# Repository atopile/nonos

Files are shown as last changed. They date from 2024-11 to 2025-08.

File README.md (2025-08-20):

# NONOS

### The Open Source Smart Speaker

<div align="center">
  
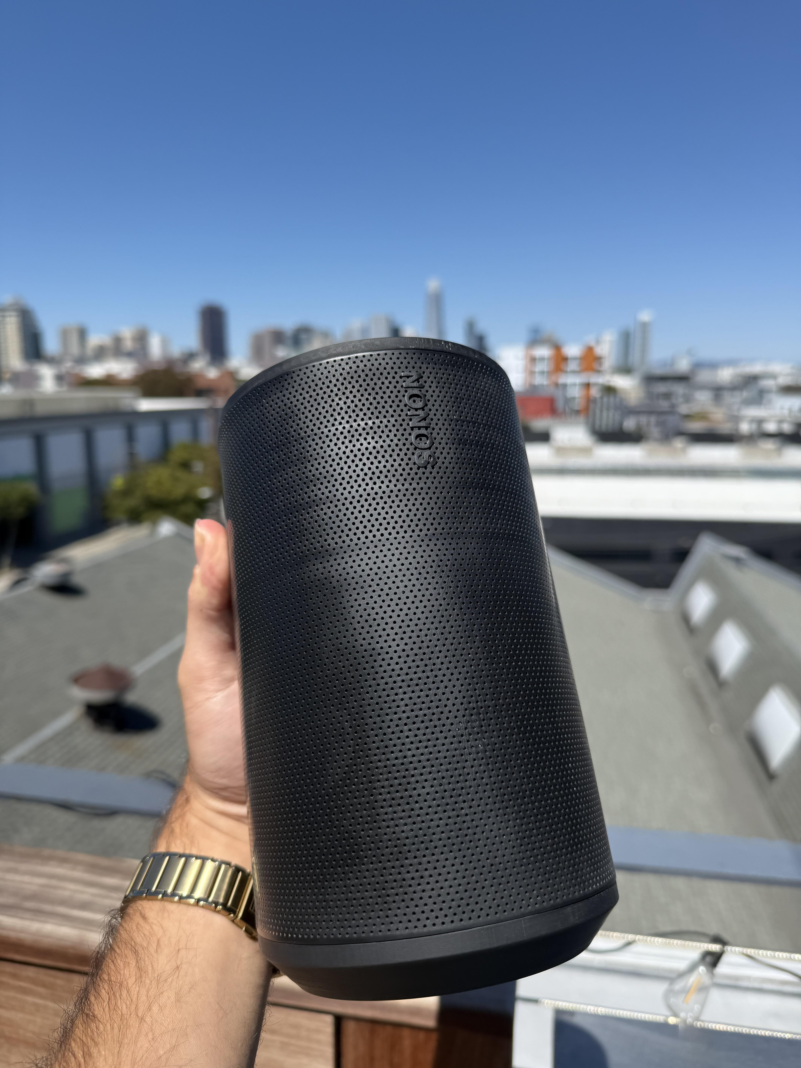
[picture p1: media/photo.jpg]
NONOS Smart Speaker
  
  
  **Premium Sound • Privacy First • Fully Hackable**
  
  
  
  
  
</div>

---

## 🎵 Experience Audio Freedom

NONOS is a premium smart speaker that puts you in control. It delivers exceptional sound quality while respecting your privacy, and its hardware is described declaratively in lightweight `.ato` files.

### ✨ Key Features

<table>
<tr>
<td width="50%">

**🔊 Audiophile-Grade Sound**

- Dual-driver system with dedicated tweeter and full-range speaker
- Texas Instruments TAS5825M Class-D amplifier
- Analog Devices ADAU145x DSP for pristine audio processing
- I2S digital audio interface for lossless playback

</td>
<td width="50%">

**🧠 Powerful Computing**

- Raspberry Pi CM5 module at its heart
- Gigabit Ethernet connectivity
- USB-C with Power Delivery support
- Multiple I2C, UART, and GPIO interfaces

</td>
</tr>
<tr>
<td width="50%">

**🎨 Interactive Design**

- 23 SK6805 addressable RGB LEDs
- Capacitive touch controls with volume slider
- NFC tap-to-pair functionality
- Minimalist cylindrical form factor

</td>
<td width="50%">

**⚡ Smart Power Management**

- USB-C Power Delivery (20V input)
- Efficient buck converters (5V & 3.3V rails)
- STUSB4500 PD controller
- Low standby power consumption

</td>
</tr>
</table>

---

## 🎶 Software Features

### Streaming Services

Connect and play from all your favorite sources:

- **Spotify Connect** - Stream directly from the Spotify app
- **AirPlay** - Native support for Apple devices
- **Bluetooth Audio** - Auto-pairing A2DP streaming
- **Local Playback** - Play your music library via network shares

### Smart Controls

Intuitive touch interface with gesture support:

- **Play/Pause** - Center button for media control
- **Track Navigation** - Skip tracks or seek within songs
- **Volume Slider** - 5-position touch slider with double-tap gestures
  - Double-tap position 0 for mute
  - Double-tap position 4 for +6dB boost
- **Configurable EQ** - 15-band parametric equalizer

### Audio Excellence

Professional-grade DSP processing:

- **Crossover Networks** - Optimized for dual-driver configuration
- **Dynamic Range Control** - Independent limiting for highs and lows
- **Mid-Side Processing** - Adjustable stereo width
- **PipeWire Integration** - Low-latency audio with automatic resampling

---

## 🎛️ Hardware Highlights

### Audio Processing Pipeline

```
CM5 (Digital Audio) → I2S → ADAU145x DSP → I2S → TAS5825M Amplifier → Speakers
```

### Interactive Hat Module

- **NFC**: PN5321 for instant device pairing
- **Touch**: CAP1188 capacitive sensor (3 buttons + 5-position slider)
- **LEDs**: 23x SK6805 RGB LEDs in a circular array
- **Level Shifting**: Ensures reliable 3.3V/5V communication

### Debug Headers

Three Saleae-compatible headers for easy development:

- UART console access
- I2C bus monitoring
- I2S audio stream analysis

### Printed Circuit Boards

#### Mainboard

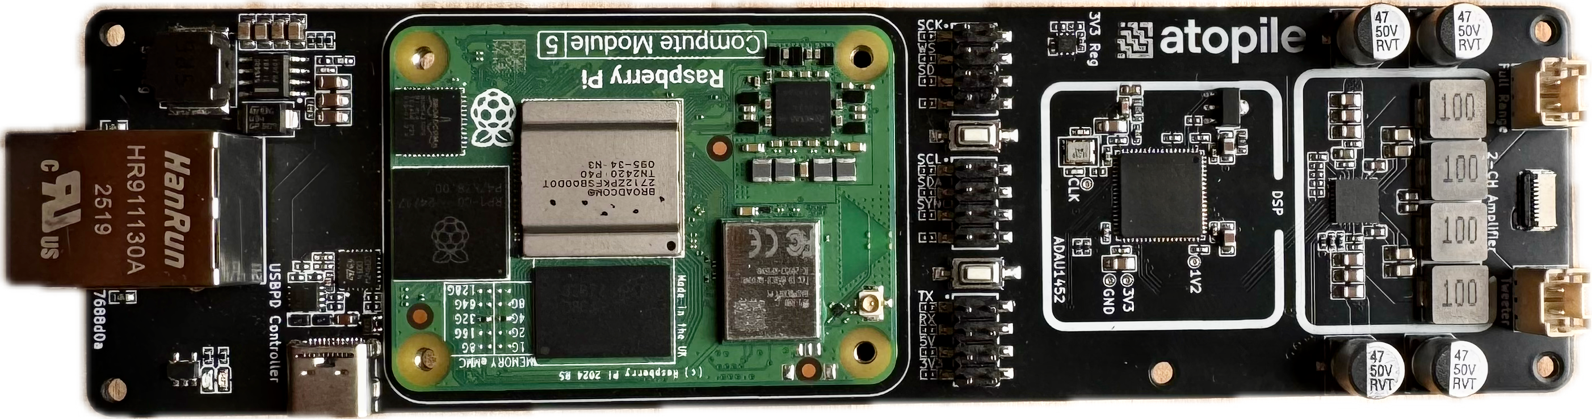
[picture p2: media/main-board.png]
NONOS Mainboard Render


- **atopile module:** `NONOS` (`elec/src/nonos.ato`)
- USB-C Power Delivery input via **STUSB4500** (up to 20 V)
- Power tree: **TPS54560x** 5 V buck ➜ **TLV75901** 3 .3 V LDO
- **Raspberry Pi CM5** compute module
- **ADAU145x** audio DSP ➜ **TAS5825M** 2-channel Class-D amplifier
- 10-pin mezzanine connector to the Hat
- Connectors for full-range & tweeter speakers
- Three Saleae-compatible debug headers (UART, I2C, I2S)

#### Control Hat

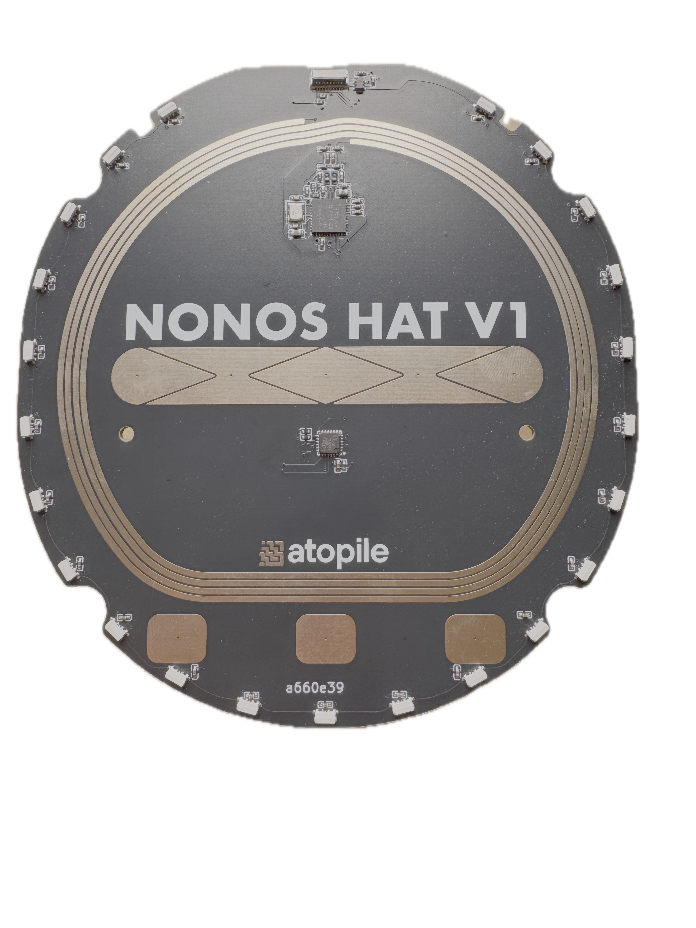
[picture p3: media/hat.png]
Interactive Hat PCB


- **atopile module:** `Hat` (`elec/src/hat.ato`)
- **PN5321** NFC transceiver with custom button-antenna
- **CAP1188** capacitive touch sensor (3 buttons + 5-point slider)
- 23× **SK6805** side-emitting RGB LEDs arranged in a ring
- **74LVC1T45** level-shifter for reliable 5 V LED data
- Powered from 3 .3 V (logic) & 5 V (LEDs) supplied by the mainboard
- 10-pin mezzanine connector mates directly with the mainboard

---

## 🛠️ Hardware Design

The hardware is captured in concise `.ato` design files (powered by [atopile](https://atopile.io)).

```ato
module NONOS:
    """
    An opensource sonos era 100 clone
    """

    # Core Components
    cm5 = new CM5
    amplifier = new Texas_Instruments_TAS5825MRHBR_driver
    dsp = new Analog_Devices_ADAU145x_driver
    pd_controller = new STUSB4500

    # Smart Power Distribution
    pd_controller.power_out ~ power_20v
    power_20v ~> regulator_5v ~> power_5v
    power_5v ~> regulator_3v3 ~> power_3v3
```

### 📁 Project Structure

```
nonos/
├── elec/
│   └── src/
│       ├── nonos.ato      # Main speaker module
│       ├── hat.ato        # Touch/LED/NFC interface
│       └── parts/         # Component library
├── firmware/              # CM5 software stack
├── mechanical/            # Enclosure designs
└── docs/                  # Build instructions
```

---

## 🎚️ Audio Tuning

<table>
<tr>
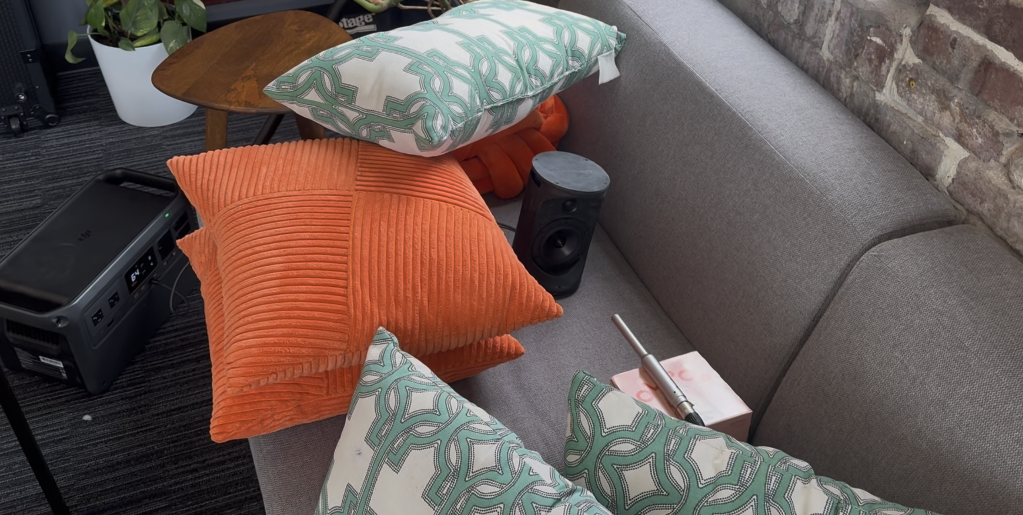
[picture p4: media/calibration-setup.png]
Calibration setup
<td width="33%"></td>
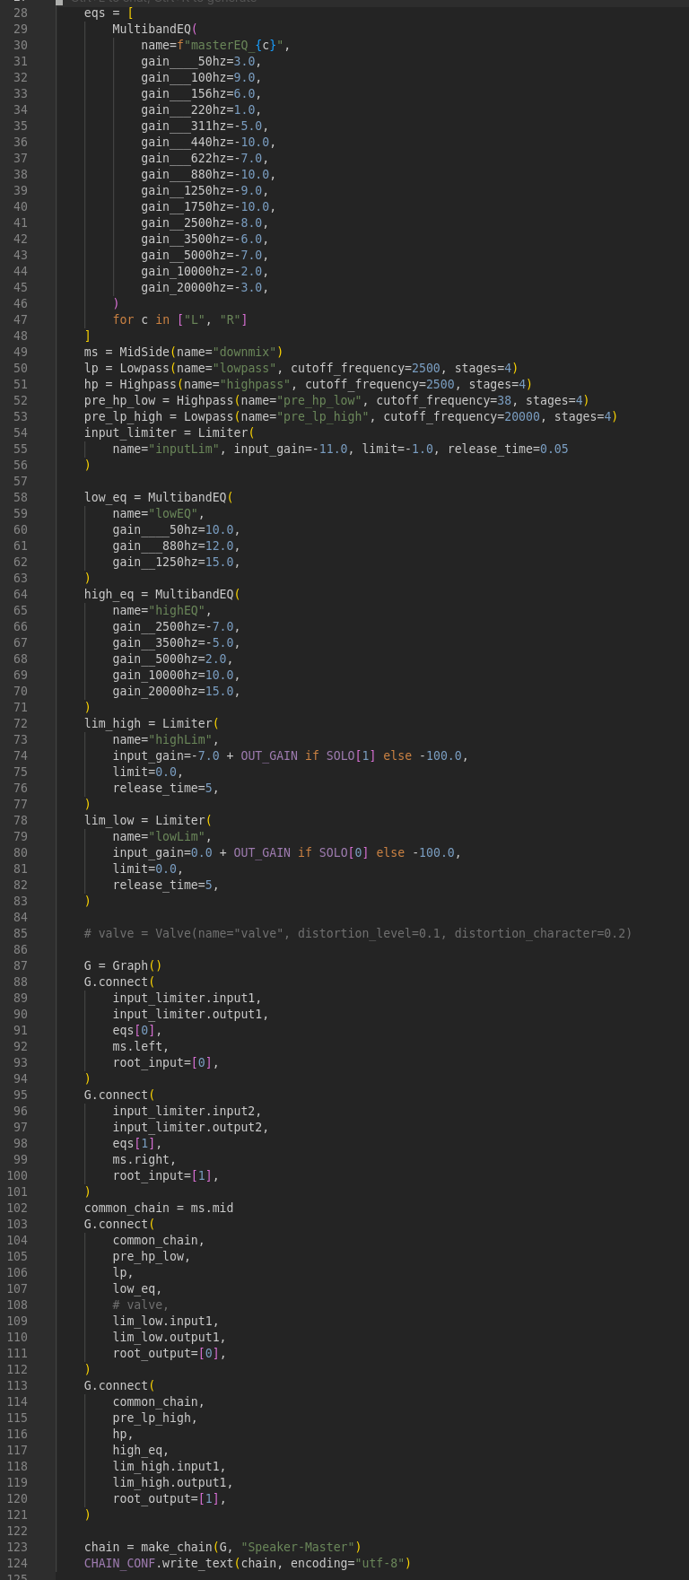
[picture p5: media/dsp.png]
DSP tuning
<td width="33%"></td>
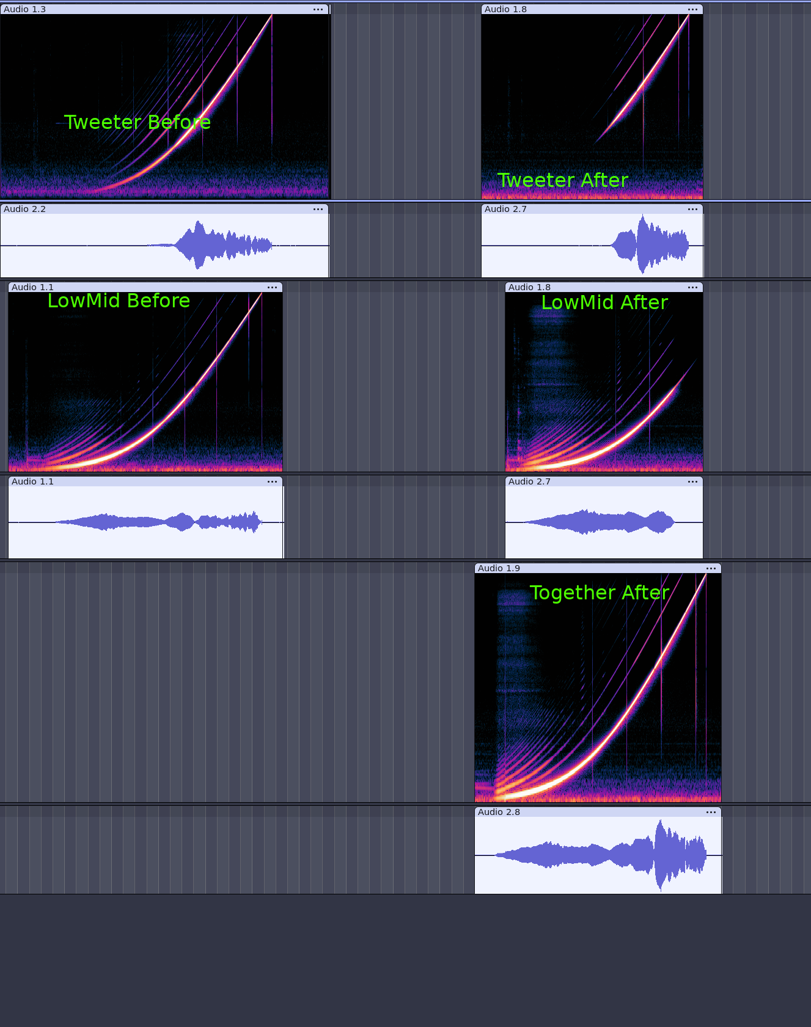
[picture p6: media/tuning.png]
Frequency response
<td width="33%"></td>
</tr>
</table>

Using a calibrated reference microphone we swept each driver, loaded the recordings into **Audacity** to eyeball the bumps and dips, then built FIR/biquad filters in SigmaStudio and dialed-in a 2-way crossover with gentle EQ to flatten the combined response. The whole process took about **20 heroic minutes**—roughly _twice_ the time it looks like Sonos spends on some of their launch-day tunings 😉.

---

## 🚀 Getting Started

### Prerequisites

- **[atopile](https://docs.atopile.io/atopile/quickstart)** compiler installed
- KiCad 8.0 or later (for PCB viewing/editing)
- Basic SMD soldering equipment

### Building NONOS

1. **Clone the repository**

   ```bash
   git clone https://github.com/atopile/nonos
   cd nonos
   ```

2. **Compile the hardware design**

   ```bash
   ato build
   ```

3. **Generate manufacturing files**

   ```bash
   ato build -t all
   ```

4. **Order PCBs and components**
   - Upload gerbers from `/build` to your preferred PCB manufacturer
   - Use the generated BOM for component ordering

---

## 🤝 Contributing

We love contributions! Whether it's:

- 🐛 Bug fixes
- ✨ New features
- 📚 Documentation improvements
- 🎨 Design enhancements

---

## 📄 License

NONOS is open source hardware, released under the MIT License. See [LICENSE](LICENSE) for details.

---

## 🌟 Acknowledgments

Built with ❤️ using **[atopile](https://atopile.io)** - the language that's revolutionizing hardware design.

Special thanks to the atopile community for making hardware development accessible to everyone.

---

<div align="center">
  
**Ready to build your own NONOS?**

[📖 Read the Docs](https://github.com/atopile/nonos) • [💬 Join Discord](https://discord.gg/7XSb5zTyfr) • [⭐ Star on GitHub](https://github.com/atopile/nonos)

</div>

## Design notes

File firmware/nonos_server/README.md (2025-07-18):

# Setup

```bash
# rsync nonos_server to nonos
rsync -a nonos_server nonos:
ssh nonos "cd nonos_server && ./setup.sh"
```

## Bluetooth

Enable `FastConnectable=y` in `/etc/bluetooth/main.conf`
Make pairable and trust all devices:

Not sure about those:

```
[General]
AutoEnable=true
Class = 0x200414
DiscoverableTimeout = 0
PairableTimeout = 0
JustWorksRepairing = always
```

## Packages

TODO

- pipewire setup
- spotifyd
- shairplay
- ...

# Test

```bash
speaker-test -Dasymed -c2 -t sine -f 1000 -F S32_LE
```

## Touch

- builtin driver (hat.dts) does not register key presses
- seems to be related to calibration not working
- multitouch does not work

# Broken

- bluetooth only works after login with ssh
- vnc stuff, see setup.sh (needs manual vncpasswd set)

# NOTES

- want usb bt dongle
- undervoltages

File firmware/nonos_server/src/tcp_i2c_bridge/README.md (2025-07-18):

# TCP-I2C Bridge

Modern Python implementation of TCP-I2C adapter with low-latency focus, comprehensive logging, and protocol dumping capabilities.

## Features

- **Modern Python Architecture**: Built with Python 3.11+, using modern libraries like `typer`, `structlog`, `pydantic`, and `asyncio`
- **Low-latency Design**: Async TCP server with `TCP_NODELAY` for minimal latency
- **Protocol Compatibility**: Fully compatible with the original C implementation
- **Comprehensive Logging**: Structured logging with rich console output
- **Protocol Dumping**: Dumps all network and I2C layer transactions to files
- **Multiple Backends**: Debug backend for testing, SMBus backend for hardware
- **Well-tested**: Comprehensive test suite with pytest and pytest-asyncio

## Installation

```bash
# Clone the repository
git clone <repository-url>
cd sigma_tcp

# Install with uv (recommended)
uv sync --dev

# Or install with pip
pip install -e .
```

## Usage

### Debug Mode (No Hardware Required)

```bash
# Start debug server on default port 8086
tcp-i2c-bridge debug

# Start on specific port with debug logging
tcp-i2c-bridge debug --port 8087 --log-level DEBUG

# Enable protocol dumping
tcp-i2c-bridge debug --dump-dir ./protocol_dumps
```

### Hardware Mode (I2C Device Required)

```bash
# Connect to I2C device at address 0x48 on bus 1
tcp-i2c-bridge i2c 1 0x48

# With custom host and port
tcp-i2c-bridge i2c 1 0x48 --host 192.168.1.100 --port 8086
```

### CLI Options

```bash
# Show help
tcp-i2c-bridge --help

# Test protocol implementation
tcp-i2c-bridge test-protocol

# Show version
tcp-i2c-bridge version
```

## Protocol Specification

The TCP-I2C bridge implements a simple binary protocol:

### Header Format (8 bytes)
```
[command][total_len_hi][total_len_lo][reserved][len_hi][len_lo][addr_hi][addr_lo]
```

### Commands
- `0x0A` - READ: Read data from I2C device
- `0x0B` - WRITE: Write data to I2C device

### Read Request
```
Header: [0x0A][0x00][0x08][0x00][len_hi][len_lo][addr_hi][addr_lo]
```

### Write Request
```
Header: [0x0B][total_len_hi][total_len_lo][0x00][len_hi][len_lo][addr_hi][addr_lo]
Data: [data_bytes...]
```

### Read Response
```
Header: [0x0B][total_len_hi][total_len_lo][0x00][len_hi][len_lo][0x00][0x00]
Status: [status_byte]
Data: [data_bytes...]
```

## Architecture

```
┌─────────────────┐    ┌─────────────────┐    ┌─────────────────┐
│   TCP Client    │◄──►│   TCP Server    │◄──►│   I2C Backend   │
└─────────────────┘    └─────────────────┘    └─────────────────┘
                              │
                              ▼
                    ┌─────────────────┐
                    │ Protocol Dumper │
                    └─────────────────┘
```

### Key Components

- **TCP Server**: Async TCP server handling multiple concurrent connections
- **Protocol Handler**: Parses and validates TCP-I2C protocol packets
- **I2C Backend**: Abstraction layer for I2C communication
  - `SMBusI2CBackend`: Real hardware using Linux I2C subsystem
  - `DebugI2CBackend`: Simulated memory for testing
- **Protocol Dumper**: Logs all network and I2C transactions to files
- **Structured Logging**: Rich console output with file logging support

## Testing

```bash
# Run all tests
uv run pytest

# Run specific test categories
uv run pytest tests/test_protocol.py      # Protocol tests
uv run pytest tests/test_i2c_backend.py   # I2C backend tests
uv run pytest tests/test_integration.py   # Integration tests

# Run with coverage
uv run pytest --cov=tcp_i2c_bridge
```

## Development

### Project Structure
```
src/tcp_i2c_bridge/
├── __init__.py          # Package initialization
├── app.py               # Main application class
├── cli.py               # Typer CLI interface
├── i2c_backend.py       # I2C backend implementations
├── logging_config.py    # Logging configuration
├── protocol.py          # Protocol definitions
├── protocol_dumper.py   # Protocol dumping functionality
└── server.py            # TCP server implementation

tests/
├── test_protocol.py     # Protocol unit tests
├── test_i2c_backend.py  # I2C backend tests
├── test_server.py       # Server tests
└── test_integration.py  # Integration tests
```

### Code Quality

```bash
# Format code
uv run black src/ tests/

# Lint code
uv run ruff src/ tests/

# Type checking
uv run mypy src/
```

## Protocol Dumping

When enabled, the bridge creates detailed logs of all communication:

```
dumps/
└── session_20250711_114427/
    ├── network/          # Binary network packets
    ├── i2c/              # Binary I2C transactions
    ├── network.log       # Network layer log
    ├── i2c.log           # I2C layer log
    └── summary.txt       # Session summary
```

## Performance Characteristics

- **Latency**: Sub-millisecond response times with TCP_NODELAY
- **Throughput**: Supports concurrent connections with asyncio
- **Memory**: Minimal memory footprint with efficient buffering
- **Scalability**: Handles multiple simultaneous I2C operations

## Compatibility

- **Python**: 3.11+ required
- **Operating System**: Linux (for hardware I2C access)
- **I2C Devices**: Compatible with standard Linux I2C subsystem (`/dev/i2c-*`)
- **Protocol**: 100% compatible with original C implementation

## Example Client Code

```python
import socket
import struct

# Connect to bridge
sock = socket.socket(socket.AF_INET, socket.SOCK_STREAM)
sock.connect(('localhost', 8086))

# Write 4 bytes to address 0x1000
write_header = struct.pack(">BHHBBH", 0x0B, 12, 0, 0, 4, 0x1000)
write_data = b"test"
sock.send(write_header + write_data)

# Read 4 bytes from address 0x1000
read_header = struct.pack(">BHHBBH", 0x0A, 8, 0, 0, 4, 0x1000)
sock.send(read_header)

# Receive response
response = sock.recv(1024)
# Parse response...

sock.close()
```

## License

This project maintains compatibility with the original C implementation's licensing terms.

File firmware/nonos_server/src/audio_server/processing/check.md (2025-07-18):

```
Plugin Name: "Fast Lookahead limiter"
Plugin Label: "fastLookaheadLimiter"
Plugin Unique ID: 1913
Maker: "Steve Harris <steve@plugin.org.uk>"
Copyright: "GPL"
Must Run Real-Time: No
Has activate() Function: Yes
Has deactivate() Function: No
Has run_adding() Function: Yes
Environment: Normal or Hard Real-Time
Ports:	"Input gain (dB)" input, control, -20 to 20, default 0
	"Limit (dB)" input, control, -20 to 0, default 0
	"Release time (s)" input, control, 0.01 to 2, default 0.5075
	"Attenuation (dB)" output, control, 0 to 70
	"Input 1" input, audio
	"Input 2" input, audio
	"Output 1" output, audio
	"Output 2" output, audio
	"latency" output, control

Plugin Name: "Glame Highpass Filter"
Plugin Label: "highpass_iir"
Plugin Unique ID: 1890
Maker: "Alexander Ehlert <mag@glame.de>"
Copyright: "GPL"
Must Run Real-Time: No
Has activate() Function: Yes
Has deactivate() Function: No
Has run_adding() Function: Yes
Environment: Normal or Hard Real-Time
Ports:	"Cutoff Frequency" input, control, 0.0001*srate to 0.45*srate, default 0.000819036*srate, logarithmic
	"Stages(2 poles per stage)" input, control, 1 to 10, default 1, integer
	"Input" input, audio
	"Output" output, audio

Plugin Name: "Glame Lowpass Filter"
Plugin Label: "lowpass_iir"
Plugin Unique ID: 1891
Maker: "Alexander Ehlert <mag@glame.de>"
Copyright: "GPL"
Must Run Real-Time: No
Has activate() Function: Yes
Has deactivate() Function: No
Has run_adding() Function: Yes
Environment: Normal or Hard Real-Time
Ports:	"Cutoff Frequency" input, control, 0.0001*srate to 0.45*srate, default 0.0549426*srate, logarithmic
	"Stages(2 poles per stage)" input, control, 1 to 10, default 1, integer
	"Input" input, audio
	"Output" output, audio

Plugin Name: "Matrix: Stereo to MS"
Plugin Label: "matrixStMS"
Plugin Unique ID: 1420
Maker: "Steve Harris <steve@plugin.org.uk>"
Copyright: "GPL"
Must Run Real-Time: No
Has activate() Function: No
Has deactivate() Function: No
Has run_adding() Function: Yes
Environment: Normal or Hard Real-Time
Ports:	"Left" input, audio
	"Right" input, audio
	"Mid" output, audio
	"Side" output, audio

Plugin Name: "Triple band parametric with shelves"
Plugin Label: "triplePara"
Plugin Unique ID: 1204
Maker: "Steve Harris <steve@plugin.org.uk>"
Copyright: "GPL"
Must Run Real-Time: No
Has activate() Function: Yes
Has deactivate() Function: No
Has run_adding() Function: Yes
Environment: Normal or Hard Real-Time
Ports:	"Low-shelving gain (dB)" input, control, -70 to 30, default 0
	"Low-shelving frequency (Hz)" input, control, 0.0001*srate to 0.49*srate, default 0.0001*srate, logarithmic
	"Low-shelving slope" input, control, 0 to 1, default 0.5
	"Band 1 gain (dB)" input, control, -70 to 30, default 0
	"Band 1 frequency (Hz)" input, control, 0.0001*srate to 0.49*srate, default 0.00083666*srate, logarithmic
	"Band 1 bandwidth (octaves)" input, control, 0 to 4, default 1
	"Band 2 gain (dB)" input, control, -70 to 30, default 0
	"Band 2 frequency (Hz)" input, control, 0.0001*srate to 0.49*srate, default 0.007*srate, logarithmic
	"Band 2 bandwidth (octaves)" input, control, 0 to 4, default 1
	"Band 3 gain (dB)" input, control, -70 to 30, default 0
	"Band 3 frequency (Hz)" input, control, 0.0001*srate to 0.49*srate, default 0.0585662*srate, logarithmic
	"Band 3 bandwidth (octaves)" input, control, 0 to 4, default 1
	"High-shelving gain (dB)" input, control, -70 to 30, default 0
	"High-shelving frequency (Hz)" input, control, 0.0001*srate to 0.49*srate, default 0.49*srate, logarithmic
	"High-shelving slope" input, control, 0 to 1, default 0.5
	"Input" input, audio, -1 to 1
	"Output" output, audio, -1 to 1

Plugin Name: "Multiband EQ"
Plugin Label: "mbeq"
Plugin Unique ID: 1197
Maker: "Steve Harris <steve@plugin.org.uk>"
Copyright: "GPL"
Must Run Real-Time: No
Has activate() Function: Yes
Has deactivate() Function: No
Has run_adding() Function: Yes
Environment: Normal or Hard Real-Time
Ports:	"50Hz gain (low shelving)" input, control, -70 to 30, default 0
	"100Hz gain" input, control, -70 to 30, default 0
	"156Hz gain" input, control, -70 to 30, default 0
	"220Hz gain" input, control, -70 to 30, default 0
	"311Hz gain" input, control, -70 to 30, default 0
	"440Hz gain" input, control, -70 to 30, default 0
	"622Hz gain" input, control, -70 to 30, default 0
	"880Hz gain" input, control, -70 to 30, default 0
	"1250Hz gain" input, control, -70 to 30, default 0
	"1750Hz gain" input, control, -70 to 30, default 0
	"2500Hz gain" input, control, -70 to 30, default 0
	"3500Hz gain" input, control, -70 to 30, default 0
	"5000Hz gain" input, control, -70 to 30, default 0
	"10000Hz gain" input, control, -70 to 30, default 0
	"20000Hz gain" input, control, -70 to 30, default 0
	"Input" input, audio
	"Output" output, audio
	"latency" output, control

Plugin Name: "Valve saturation"
Plugin Label: "valve"
Plugin Unique ID: 1209
Maker: "Steve Harris <steve@plugin.org.uk>"
Copyright: "GPL"
Must Run Real-Time: No
Has activate() Function: Yes
Has deactivate() Function: No
Has run_adding() Function: Yes
Environment: Normal or Hard Real-Time
Ports:	"Distortion level" input, control, 0 to 1, default 0
	"Distortion character" input, control, 0 to 1, default 0
	"Input" input, audio
	"Output" output, audio
```

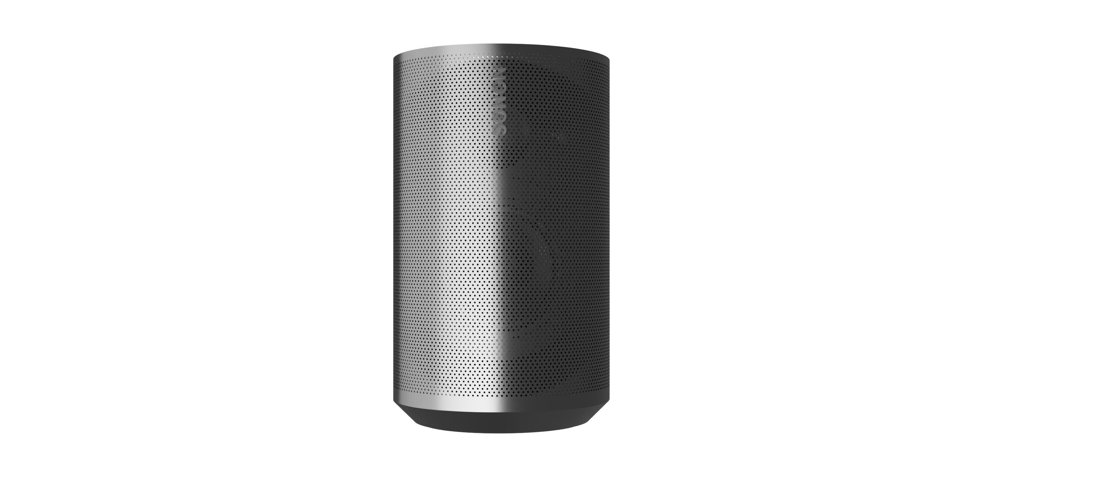
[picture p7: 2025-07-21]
media/nonos-render-front.png

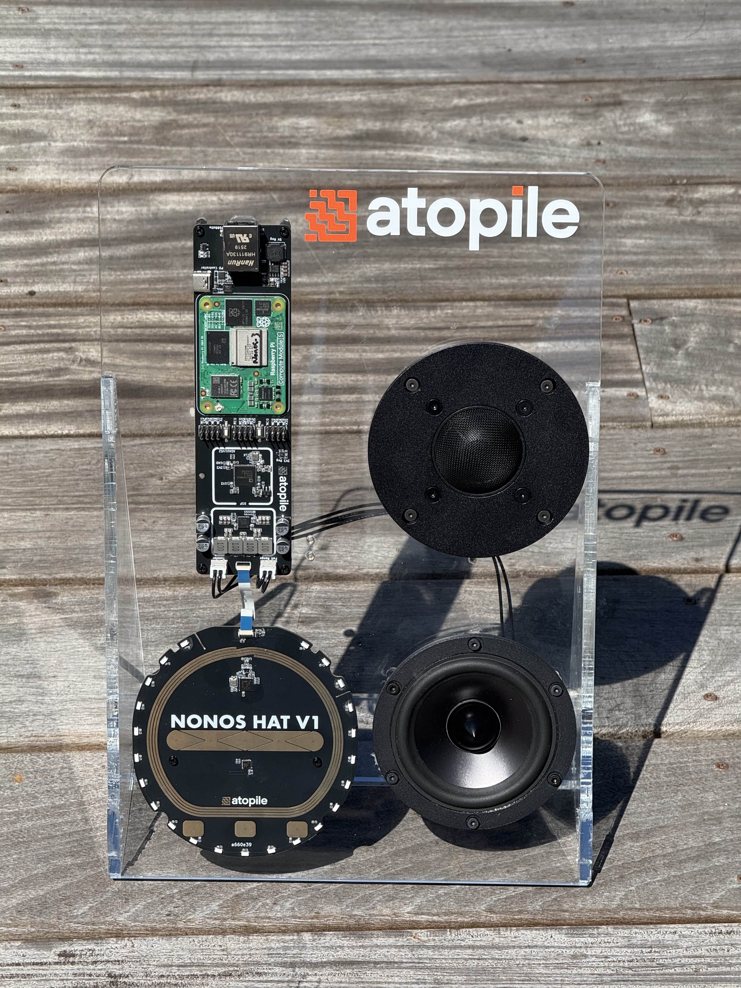
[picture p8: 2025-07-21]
media/pcbs.jpg

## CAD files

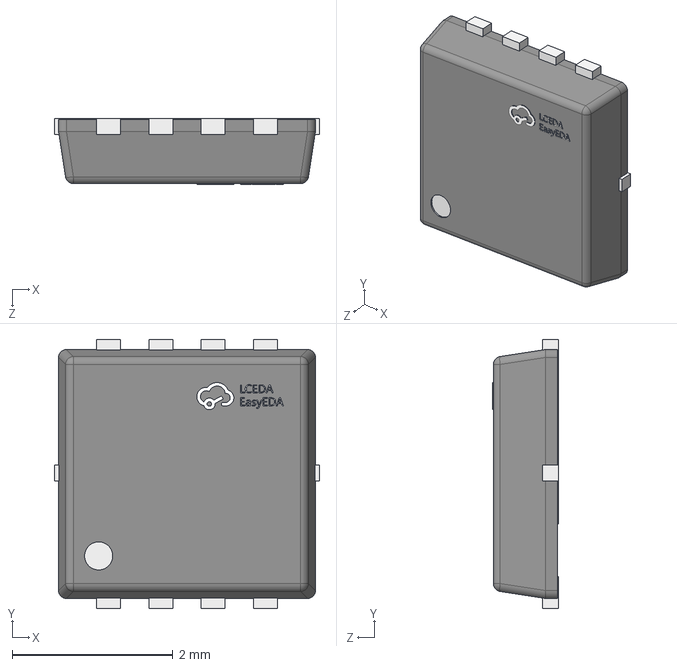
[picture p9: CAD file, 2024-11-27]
elec/src/parts/ALLPOWER_AP30P30Q/PDFN3333-8_L3.1-W3.2-H0.8-P0.65.step
3.30 x 3.35 x 0.82 mm

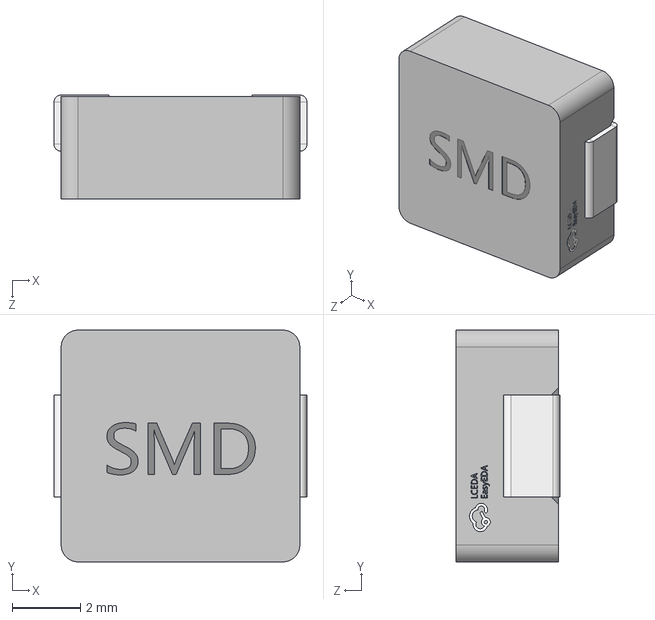
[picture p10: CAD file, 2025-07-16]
elec/src/parts/cjiang_FXL0630_100_M/IND-SMD_L7.3-W6.8-H3.0.step
7.42 x 6.80 x 3.05 mm

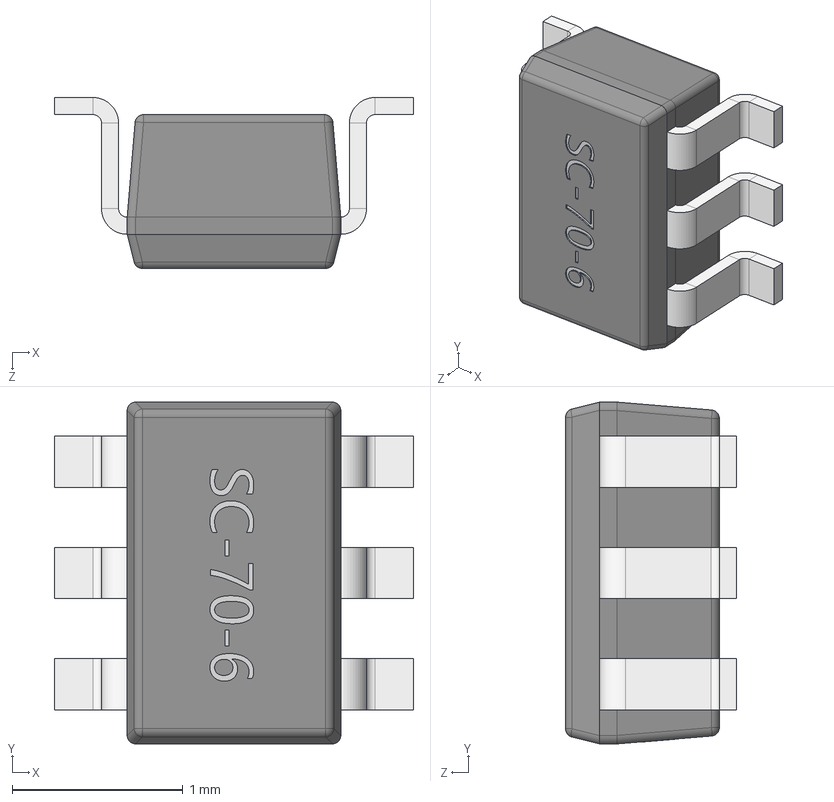
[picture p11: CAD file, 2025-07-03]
elec/src/parts/Diodes_Incorporated_74LVC1T45DW_7/SC-70-6_L2.0-W1.3-H1.0-P0.65.step
2.10 x 2.00 x 1.00 mm

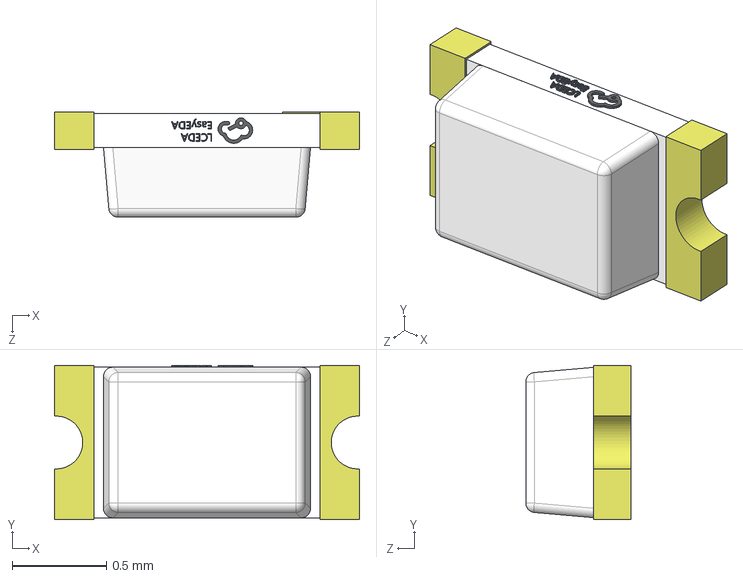
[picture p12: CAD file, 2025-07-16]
elec/src/parts/Everlight_Elec_19_213_Y2C_CQ2R2L_3T_CY/LED0603-RD-YELLOW.step
1.62 x 0.82 x 0.56 mm

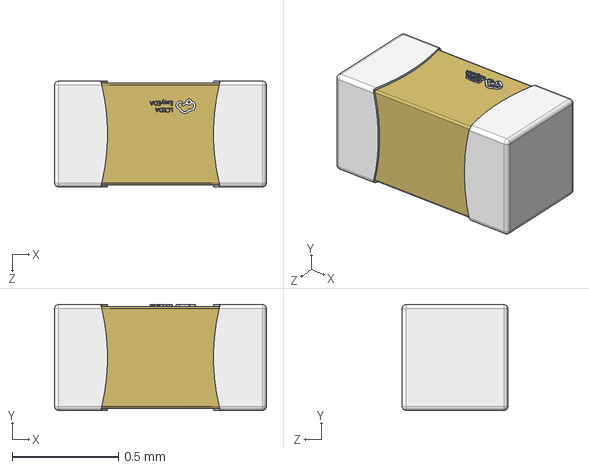
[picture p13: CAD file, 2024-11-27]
elec/src/parts/FH_0402CG150J500NT/C0402_L1.0-W0.5-H0.5.step
1.00 x 0.5 x 0.5 mm

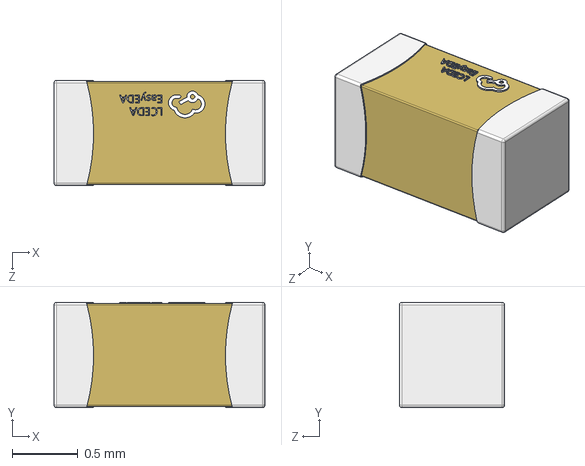
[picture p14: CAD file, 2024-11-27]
elec/src/parts/FH_0603B562K500NT/C0603_L1.6-W0.8-H0.8.step
1.60 x 0.8 x 0.8 mm

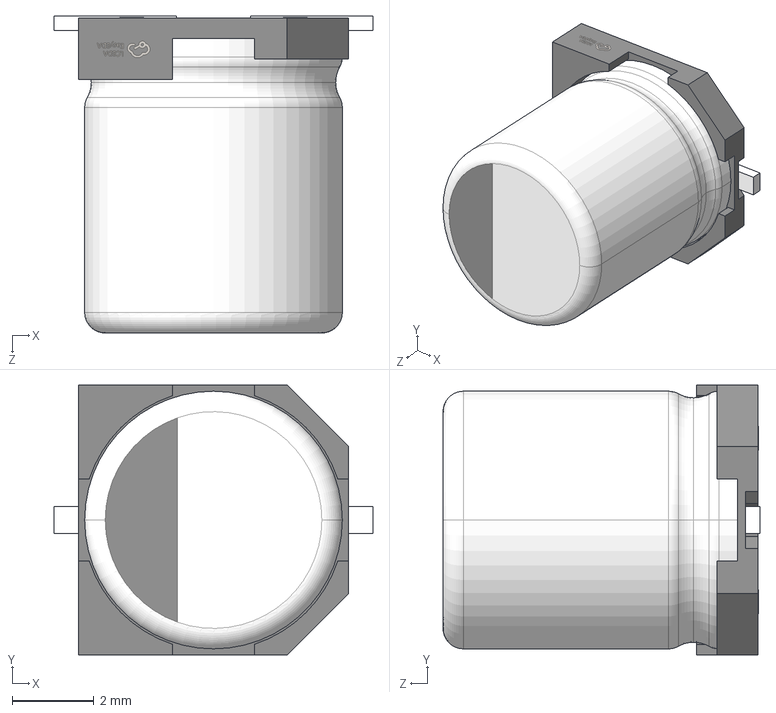
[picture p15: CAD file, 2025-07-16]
elec/src/parts/Honor_Elec_RVT1H470M0607/CAP-SMD_BD6.3-L6.6-W6.6-FD.step
7.80 x 6.60 x 7.75 mm

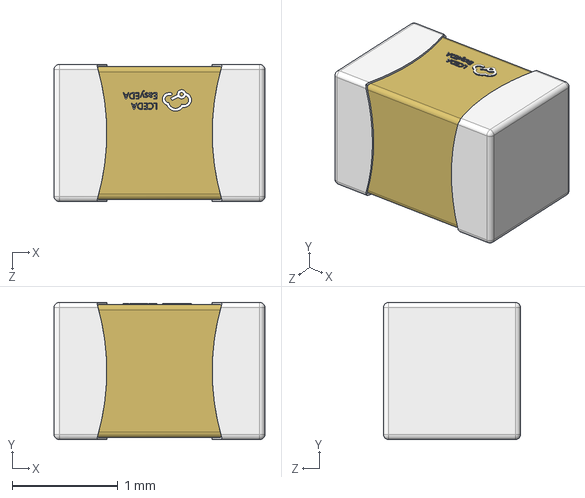
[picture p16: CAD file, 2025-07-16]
elec/src/parts/HRE_CGA0805X7R475K350MT/C0805_L2.0-W1.3-H1.3.step
2.00 x 1.30 x 1.30 mm

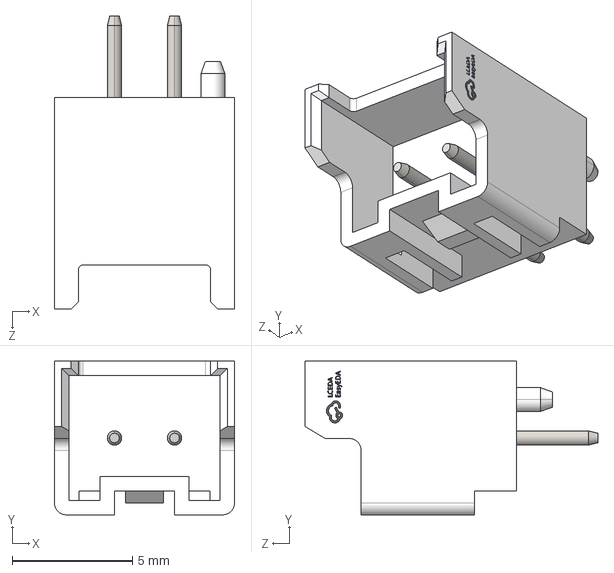
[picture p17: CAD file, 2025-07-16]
elec/src/parts/JST_Sales_America_B02B_XASK_1_A_LF__SN/CONN-TH_B02B-XASK-1-A-LF-SN.step
7.50 x 6.40 x 12.2 mm

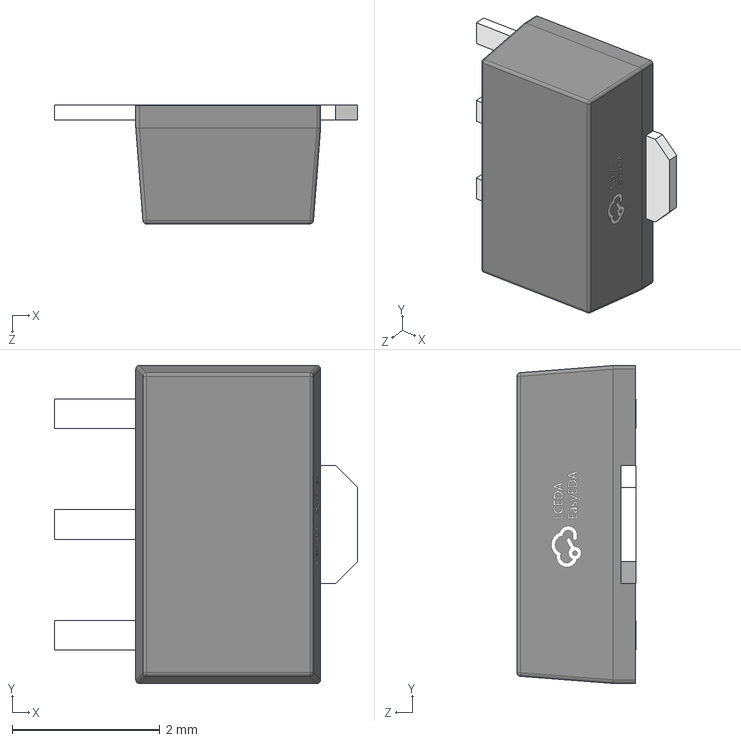
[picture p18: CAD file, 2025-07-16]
elec/src/parts/Nexperia_PBSS5350X_115/SOT-89-3_L4.3-W2.5-H1.6-LS4.1-P1.50.step
4.10 x 4.30 x 1.61 mm

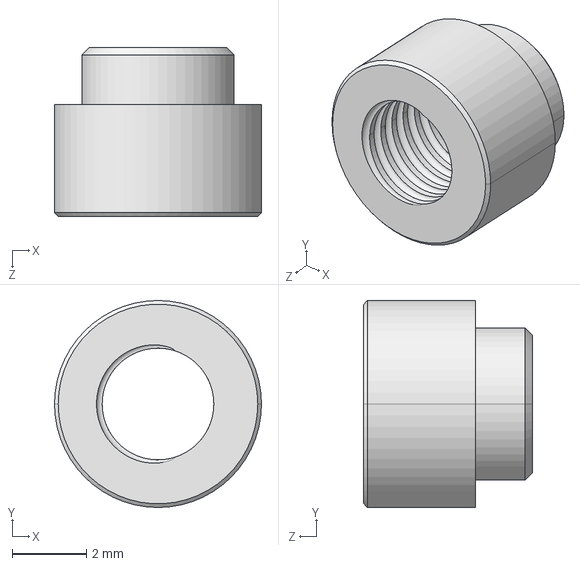
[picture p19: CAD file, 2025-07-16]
elec/src/parts/Sinhoo_SMTSO2515CTJ/SMD_BD5.6-D4.1.STEP
5.56 x 5.56 x 4.53 mm

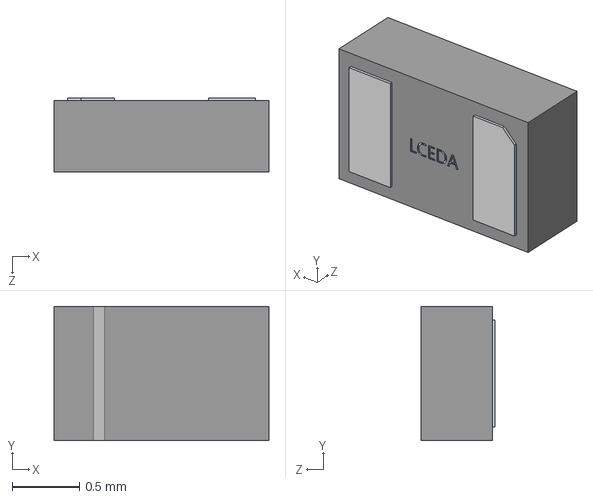
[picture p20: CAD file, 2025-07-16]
elec/src/parts/STMicroelectronics_ESDA25P35_1U1M/DFN1610-2_L1.6-W1.0-P1.05-RD.STEP
1.60 x 1.00 x 0.55 mm

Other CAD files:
elec/src/parts/Hubei_KENTO_Elec_KT_0603G/LED0603-RD-YELLOW.STEP
elec/src/parts/STMicroelectronics_ESDA25W/SOT-323-3_L2.0-W1.3-H1.0-LS2.1-P1.30.step
elec/src/parts/STMicroelectronics_STPS340U/SMB_L4.6-W3.6-LS5.3-RD.step
elec/src/parts/STMicroelectronics_STUSB4500QTR/57.STEP
elec/src/parts/Sunlord_SWPA8040S5R6NT/IND-SMD_L8.0-W8.0-H4.2.STEP
elec/src/parts/TDK_NLV32T_R56J_EF/IND-SMD_L3.2-W2.5.step
elec/src/parts/TE_Connectivity_1_2328702_0/FPC-SMD_10P-P0.50_HDGC_0.5K-HX-10PWB.step
elec/src/parts/Texas_Instruments_SN74LVC1G07DBVR/SOT-23-5_L2.9-W1.6-H1.1-LS2.8-P0.95.step
elec/src/parts/Texas_Instruments_TLV75901PDRVR/WSON-6_L2.0-W2.0-H0.8-P0.65.step
elec/src/parts/Texas_Instruments_TPS54560DDAR/SOIC-8_L4.9-W3.9-H1.7-LS6.0-P1.27.step
elec/src/parts/UNI_ROYAL_0402WGF4700TCE/R0402_L1.0-W0.5-H0.4.step
elec/src/parts/UNI_ROYAL_0603WAF0000T5E/R0603.STEP
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

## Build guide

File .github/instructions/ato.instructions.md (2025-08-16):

---
description: ato is a declarative DSL to design electronics (PCBs) with.
applyTo: *.ato, ato.yaml
---

ato is a declarative DSL to design electronics (PCBs) with.
It is part of the atopile project.
Atopile is run by the vscode/cursor/windsurf extension.
The CLI (which is invoked by the extension) actually builds the project.

# Not available in ato

- if statements
- while loops
- functions (calls or definitions)
- classes
- objects
- exceptions
- generators

# Ato Syntax

ato sytax is heavily inspired by Python, but fully declarative.
ato thus has no procedural code, and no side effects.

## Examples of syntax

```ato
#pragma text
#pragma func("X")
# enable for loop syntax feature:
#pragma experiment("FOR_LOOP)

# --- Imports ---
# Standard import (newline terminated)
import ModuleName

# Import with multiple modules (newline terminated)
import Module1, Module2.Submodule

# Import from a specific file/source (newline terminated)
from "path/to/source.ato" import SpecificModule

# Multiple imports on one line (semicolon separated)
import AnotherModule; from "another/source.ato" import AnotherSpecific

# Deprecated import form (newline terminated)
# TODO: remove when unsupported
import DeprecatedModule from "other/source.ato"

# --- Top-level Definitions and Statements ---

pass
pass;

"docstring-like statement"
"docstring-like statement";

top_level_var = 123

# Compound statement
pass; another_var = 456; "another docstring"

# Block definitions
component MyComponent:
    # Simple statement inside block (newline terminated)
    pass

    # Multiple simple statements on one line (semicolon separated)
    pass; internal_flag = True

module AnotherBaseModule:
    pin base_pin
    base_param = 10

interface MyInterface:
    pin io

module DemoModule from AnotherBaseModule:
    # --- Declarations ---
    pin p1              # Pin declaration with name
    pin 1               # Pin declaration with number
    pin "GND"           # Pin declaration with string
    signal my_signal    # Signal definition
    a_field: AnotherBaseModule      # Field declaration with type hint

    # --- Assignments ---
    # Newline terminated:
    internal_variable = 123

    # Semicolon separated on one line:
    var_a = 1; var_b = "string"

    # Cumulative assignment (+=, -=) - Newline terminated
    value = 1
    value += 1; value -= 1

    # Set assignment (|=, &=) - Newline terminated
    flags |= 1; flags &= 2

    # --- Connections ---
    p1 ~ base_pin
    mif ~> bridge
    mif ~> bridge ~> bridge
    mif ~> bridge ~> bridge ~> mif
    bridge ~> mif
    mif <~ bridge
    mif <~ bridge <~ bridge
    mif <~ bridge <~ bridge <~ mif
    bridge <~ mif

    # Semicolon separated on one line:
    p_multi1 ~ my_signal; p_multi2 ~ sig_multi1

    # --- Retyping ---
    instance.x -> AnotherBaseModule

    # --- Instantiation ---
    instance = new MyComponent
    container = new MyComponent[10]
    templated_instance_a = new MyComponent
    templated_instance_b = new MyComponent<int_=1>
    templated_instance_c = new MyComponent<float_=2.5>
    templated_instance_d = new MyComponent<string_="hello">
    templated_instance_e = new MyComponent<int_=1, float_=2.5, string_="hello">
    templated_instance_f = new MyComponent<int_=1, float_=2.5, string_="hello", bool_=True>

    # Semicolon separated instantiations (via assignment):
    inst_a = new MyComponent; inst_b = new AnotherBaseModule

    # --- Traits ---
    trait trait_name
    trait trait_name<int_=1>
    trait trait_name<float_=2.5>
    trait trait_name<string_="hello">
    trait trait_name<bool_=True>
    trait trait_name::constructor
    trait trait_name::constructor<int_=1>

    # Semicolon separated on one line:
    trait TraitA; trait TraitB::constructor; trait TraitC<arg_=1>

    # --- Assertions ---
    assert x > 5V
    assert x < 10V
    assert 5V < x < 10V
    assert x >= 5V
    assert x <= 10V
    assert current within 1A +/- 10mA
    assert voltage within 1V +/- 10%
    assert resistance is 1kohm to 1.1kohm

    # Semicolon separated on one line:
    assert x is 1V; assert another_param is 2V

    # --- Loops ---
    for item in container:
        item ~ p1

    # For loop iterating over a slice
    for item in container[0:4]:
        pass
        item.value = 1; pass

    # For loop iterating over a list literal of field references
    for ref in [p1, x.1, x.GND]:
        pass

    # --- References and Indexing ---
    # Reference with array index assignment
    array_element = container[3]

    # --- Literals and Expressions ---
    # Integer
    int_val = 100
    neg_int_val = -50
    hex_val = 0xF1
    bin_val = 0b10
    oct_val = 0o10
    # Float
    float_val = 3.14
    # Physical quantities
    voltage: V = 5V
    resistance: ohm = 10kohm
    capacitance: F = 100nF
    # Bilateral tolerance
    tolerance_val = 1kohm +/- 10%
    tolerance_abs = 5V +/- 500mV
    tolerance_explicit_unit = 10A +/- 1A
    # Bounded quantity (range)
    voltage_range = 3V to 3.6V
    # Boolean
    is_enabled = True
    is_active = False
    # String
    message = "Hello inside module"

    # Arithmetic expressions
    sum_val = 1 + 2
    diff_val = 10 - 3ohm
    prod_val = 5 * 2mA
    div_val = 10V / 2kohm # Results in current
    power_val = 2**3
    complex_expr = (5 + 3) * 2 - 1
    flag_check = state | MASK_VALUE

    # Comparisons
    assert voltage within voltage_range
    assert length <= 5mm
    assert height >= 2mm

# --- Multi-line variations ---
pass; nested_var=1; another=2

complex_assignment = (
    voltage + resistance
    * capacitance
)

```

## G4 Grammar

```g4
parser grammar AtoParser;

options {
	superClass = AtoParserBase;
	tokenVocab = AtoLexer;
}

file_input: (NEWLINE | stmt)* EOF;

pragma_stmt: PRAGMA;

stmt: simple_stmts | compound_stmt | pragma_stmt;
simple_stmts:
	simple_stmt (SEMI_COLON simple_stmt)* SEMI_COLON? NEWLINE;
simple_stmt:
	import_stmt
	| dep_import_stmt
	| assign_stmt
	| cum_assign_stmt
	| set_assign_stmt
	| connect_stmt
	| directed_connect_stmt
	| retype_stmt
	| pin_declaration
	| signaldef_stmt
	| assert_stmt
	| declaration_stmt
	| string_stmt
	| pass_stmt
	| trait_stmt;

compound_stmt: blockdef | for_stmt;

blockdef: blocktype name blockdef_super? COLON block;
// TODO @v0.4 consider ()
blockdef_super: FROM type_reference;
// TODO @v0.4 consider removing component (or more explicit code-as-data)
blocktype: (COMPONENT | MODULE | INTERFACE);
block: simple_stmts | NEWLINE INDENT stmt+ DEDENT;

// TODO: @v0.4 remove the deprecated import form
dep_import_stmt: IMPORT type_reference FROM string;
import_stmt: (FROM string)? IMPORT type_reference (
		COMMA type_reference
	)*;

declaration_stmt: field_reference type_info;
field_reference_or_declaration:
	field_reference
	| declaration_stmt;
assign_stmt: field_reference_or_declaration '=' assignable;
cum_assign_stmt:
	field_reference_or_declaration cum_operator cum_assignable;
// TODO: consider sets cum operator
set_assign_stmt:
	field_reference_or_declaration (OR_ASSIGN | AND_ASSIGN) cum_assignable;
cum_operator: ADD_ASSIGN | SUB_ASSIGN;
cum_assignable: literal_physical | arithmetic_expression;

assignable:
	string
	| new_stmt
	| literal_physical
	| arithmetic_expression
	| boolean_;

retype_stmt: field_reference ARROW type_reference;

directed_connect_stmt
	: bridgeable ((SPERM | LSPERM) bridgeable)+; // only one type of SPERM per stmt allowed. both here for better error messages
connect_stmt: mif WIRE mif;
bridgeable: connectable;
mif: connectable;
connectable: field_reference | signaldef_stmt | pindef_stmt;

signaldef_stmt: SIGNAL name;
pindef_stmt: pin_stmt;
pin_declaration: pin_stmt;
pin_stmt: PIN (name | number_hint_natural | string);

new_stmt: NEW type_reference ('[' new_count ']')? template?;
new_count: number_hint_natural;

string_stmt:
	string; // the unbound string is a statement used to add doc-strings

pass_stmt:
	PASS; // the unbound string is a statement used to add doc-strings

list_literal_of_field_references:
	'[' (field_reference (COMMA field_reference)* COMMA?)? ']';

iterable_references:
	field_reference slice?
	| list_literal_of_field_references;

for_stmt: FOR name IN iterable_references COLON block;

assert_stmt: ASSERT comparison;

trait_stmt
	: TRAIT type_reference (DOUBLE_COLON constructor)? template?; // TODO: move namespacing to type_reference
constructor: name;
template: '<' (template_arg (COMMA template_arg)* COMMA?)? '>';
template_arg: name ASSIGN literal;

// Comparison operators --------------------
comparison: arithmetic_expression compare_op_pair+;

compare_op_pair:
	lt_arithmetic_or
	| gt_arithmetic_or
	| lt_eq_arithmetic_or
	| gt_eq_arithmetic_or
	| in_arithmetic_or
	| is_arithmetic_or;

lt_arithmetic_or: LESS_THAN arithmetic_expression;
gt_arithmetic_or: GREATER_THAN arithmetic_expression;
lt_eq_arithmetic_or: LT_EQ arithmetic_expression;
gt_eq_arithmetic_or: GT_EQ arithmetic_expression;
in_arithmetic_or: WITHIN arithmetic_expression;
is_arithmetic_or: IS arithmetic_expression;

// Arithmetic operators --------------------

arithmetic_expression:
	arithmetic_expression (OR_OP | AND_OP) sum
	| sum;

sum: sum (PLUS | MINUS) term | term;

term: term (STAR | DIV) power | power;

power: functional (POWER functional)?;

functional: bound | name '(' bound+ ')';

bound: atom;

// Primary elements ----------------

slice:
	'[' (slice_start? COLON slice_stop? (COLON slice_step?)?)? ']'
	// else [::step] wouldn't match
	| '[' ( DOUBLE_COLON slice_step?) ']';
slice_start: number_hint_integer;
slice_stop: number_hint_integer;
slice_step: number_hint_integer;

atom: field_reference | literal_physical | arithmetic_group;

arithmetic_group: '(' arithmetic_expression ')';

literal_physical:
	bound_quantity
	| bilateral_quantity
	| quantity;

bound_quantity: quantity TO quantity;
bilateral_quantity: quantity PLUS_OR_MINUS bilateral_tolerance;
quantity: number name?;
bilateral_tolerance: number_signless (PERCENT | name)?;

key: number_hint_integer;
array_index: '[' key ']';

// backwards compatibility for A.1
pin_reference_end: DOT number_hint_natural;
field_reference_part: name array_index?;
field_reference:
	field_reference_part (DOT field_reference_part)* pin_reference_end?;
type_reference: name (DOT name)*;
// TODO better unit
unit: name;
type_info: COLON unit;
name: NAME;

// Literals
literal: string | boolean_ | number;

string: STRING;
boolean_: TRUE | FALSE;
number_hint_natural: number_signless;
number_hint_integer: number;
number: (PLUS | MINUS)? number_signless;
number_signless: NUMBER;
```

# Most used library modules/interfaces (api of them)

```ato
interface Electrical:
    pass

interface ElectricPower:
    hv = new Electrical
    lv = new Electrical

module Resistor:
    resistance: ohm
    max_power: W
    max_voltage: V
    unnamed = new Electrical[2]

module Capacitor:
    capacitance: F
    max_voltage: V
    unnamed = new Electrical[2]

interface I2C:
    scl = new ElectricLogic
    sda = new ElectricLogic
    frequency: Hz
    address: dimensionless

interface ElectricLogic:
    line = new Electrical
    reference = new ElectricPower
```

For the rest use the atopile MCP server 
- `get_library_interfaces` to list interfaces
- `get_library_modules` to list modules
- `inspect_library_module_or_interface` to inspect the code

# Ato language features

## experimental features

Enable with `#pragma experiment("BRIDGE_CONNECT")`
BRIDGE_CONNECT: enables `p1 ~> resistor ~> p2` syntax
FOR_LOOP: enables `for item in container: pass` syntax
TRAITS: enables `trait trait_name` syntax
MODULE_TEMPLATING: enables `new MyComponent<param=literal>` syntax

## modules, interfaces, parameters, traits

A block is either a module, interface or component.
Components are just modules for code-as-data.
Interfaces describe a connectable interface (e.g Electrical, ElectricPower, I2C, etc).
A module is a block that can be instantiated.
Think of it as the ato equivalent of a class.
Parameters are variables for numbers and they work with constraints.
E.g `resistance: ohm` is a parameter.
Constrain with `assert resistance within 10kohm +/- 10%`.
It's very important to use toleranced values for parameters.
If you constrain a resistor.resistance to 10kohm there won't be a single part found because that's a tolerance of 0%.

Traits mark a module to have some kind of functionality that can be used in other modules.
E.g `trait has_designator_prefix` is the way to mark a module to have a specific designator prefix that will be used in the designator field in the footprint.

## connecting

You can only connect interfaces of the same type.
`resistor0.unnamed[0] ~ resistor0.unnamed[0]` is the way to connect two resistors in series.
If a module has the `can_bridge` trait you can use the sperm operator `~>` to bridge the module.
`led.anode ~> resistor ~> power.hv` connects the anode in series with the resistor and then the resistor in series with the high voltage power supply.

## for loop syntax

`for item in container: pass` is the way to iterate over a container.

# Ato CLI

## How to run

You run ato commands through the MCP tool.

## Packages

Packages can be found on the ato registry.
To install a package you need to run `ato add <PACKAGE_NAME>`.
e.g `ato install atopile/addressable-leds`
And then can be imported with `from "atopile/addressable-leds/sk6805-ec20.ato" import SK6805_EC20_driver`.
And used like this:

```ato
module MyModule:
    led = new SK6805_EC20_driver
```

## Footprints & Part picking

Footprint selection is done through the part choice (`ato create part` auto-generates ato code for the part).
The `pin` keyword is used to build footprint pinmaps so avoid using it outside of `component` blocks.
Preferrably use `Electrical` interface for electrical interfaces.
A lot of times it's actually `ElectricLogic` for things like GPIOs etc or `ElectricPower` for power supplies.

Passive modules (Resistors, Capacitors) are picked automatically by the constraints on their parameters.
To constrain the package do e.g `package = "0402"`.
To explictly pick a part for a module use `lcsc = "<LCSC_PART_NUMBER>"`.

# Creating a package

Package generation process:

Review structure of other pacakges.

1. Create new Directory in 'packages/packages' with naming convention '<vendor>-<device>' eg 'adi-adau145x'
2. create an ato.yaml file in the new directory with the following content:

```yaml
requires-atopile: '^0.9.0'

paths:
    src: '.'
    layout: ./layouts

builds:
    default:
        entry: <device>.ato:<device>_driver
    example:
        entry: <device>.ato:Example
```

3. Create part using tool call 'search_and_install_jlcpcb_part'
4. Import the part into the <device>.ato file
5. Read the datasheet for the device
6. Find common interfaces in the part eg I2C, I2S, SPI, Power

7. Create interfaces and connect them

power interfaces:
power*<name> = new ElectricPower
power*<name>.required = True # If critical to the device
assert power\*<name>.voltage within <minimum*operating_voltage>V to <maximum_operating_voltage>V
power*<name>.vcc ~ <device>.<vcc pin>
power\_<name>.gnd ~ <device>.<gnd pin>

i2c interfaces:
i2c = new I2C
i2c.scl.line ~ <device>.<i2c scl pin>
i2c.sda.line ~ <device>.<i2c sda pin>

spi interfaces:
spi = new SPI
spi.sclk.line ~ <device>.<spi sclk pin>
spi.mosi.line ~ <device>.<spi mosi pin>
spi.miso.line ~ <device>.<spi miso pin>

8. Add decoupling capacitors

looking at the datasheet, determine the required decoupling capacitors

eg: 2x 100nF 0402:

power_3v3 = new ElectricPower

# Decoupling power_3v3

power_3v3_caps = new Capacitor[2]
for capacitor in power_3v3_caps:
capacitor.capacitance = 100nF +/- 20%
capacitor.package = "0402"
power_3v3.hv ~> capacitor ~> power_3v3.lv

9. If device has pin configurable i2c addresses

If format is: <n x fixed address bits><m x pin configured address bits>
use addressor module:

- Use `Addressor<address_bits=N>` where **N = number of address pins**.
- Connect each `address_lines[i].line` to the corresponding pin, and its `.reference` to a local power rail.
- Set `addressor.base` to the lowest possible address and `assert addressor.address is i2c.address`.

10. Create a README.md

# <Manufacturer> <Manufacturer part number> <Short description>

## Usage

```ato
<copy in example>

```

## Contributing

Contributions to this package are welcome via pull requests on the GitHub repository.

## License

This atopile package is provided under the [MIT License](https://opensource.org/license/mit/).

11. Connect high level interfaces directly in example:

eg:

i2c = new I2C
power = new ElectricPower
sensor = new Sensor

i2c ~ sensor.i2c
power ~ sensor.power_3v3

# Additional Notes & Gotchas (generic)

- Multi-rail devices (VDD / VDDIO, AVDD / DVDD, etc.)

    - Model separate `ElectricPower` interfaces for each rail (e.g. `power_core`, `power_io`).
    - Mark each `.required = True` if the device cannot function without it, and add voltage assertions per datasheet.

- Optional interfaces (SPI vs I²C)

    - If the device supports multiple buses, pick one for the initial driver. Leave unused bus pins as `ElectricLogic` lines or expose a second interface module later.

- Decoupling guidance

    - If the datasheet shows multiple caps, model the **minimum required** set so the build passes; you can refine values/packages later.

- File / directory layout recap
    - `<vendor>-<device>/` – package root
    - `ato.yaml` – build manifest (include `default` **and** `example` targets)
    - `<device>.ato` – driver + optional example module
    - `parts/<MANUFACTURER_PARTNO>/` – atomic part + footprint/symbol/step files

These tips should prevent common "footprint not found", "pin X missing", and build-time path errors when you add new devices.

# Vibe coding a project

If the user gives you high level description of the project, use the following guide:

# How LLMs can design electronics:

#1 Rule: USE THE TOOLS. If the tools dont work, dont freak out, you are probably using them wrong. Ask for help if you get stuck.

Top level design

1. Research available packages relevant to the user requests using 'find_packages'
2. Inspect promising packages using 'inspect_package'
3. Propose packages to use for project and architucture to user, revise if needed
4. Install needed packages using 'install_package'
5. Import packages into main file
6. Create instances of packages in main module

## Power

1. Review for each package the required voltage and current (current may not be provided, use judement if nessesary)
2. Determine the power rails that need to be generated and a suitable tollerance (typically ~3-5% is acceptable)
3. Determine the input power source, typically a battery, USB connector or other power connector (eg XT30) and install relevant package
4. Find suitable regulators:
   a) if input voltage > required voltage and current is low, use an LDO package
   b) if input voltage > required voltage and current is high, use buck converter
   c) if input votlage < required voltage, use a boost converter
   d) if input voltage can be both less than or greater than input voltage, use buck boost (eg battery powered device that needs 3v3)
5. If battery powered, add charger package

Typical power architucture example with LDO:

- USB input power
- Low current output (eg microcontroller)

from "atopile/ti-tlv75901/ti-tlv75901.ato" import TLV75901_driver
from "atopile/usb-connectors/usb-connectors.ato" import USBCConn

module App:

    # Rails
    power_5v = new Power
    power_3v3 = new Power

    # Components
    ldo = new TLV75901_driver
    usb_connector = new USBCConn

    # Connections
    usb_connector.power ~ power_vbus
    power_vbus ~> ldo ~> power_3v3

## Communicaions

1. Review packages required interfaces, typically i2c, spi or ElectricLogics
2. Find suitable pins on the controller, typically a microcontroller or Linux SOC
3. Connect interfaces eg micro.i2c[0] ~ sensor.i2c

## Development process notes

- After making changes, be sure to use 'build_project' to update the PCB
- Builds will often generate errors/warnings, these should be reviewed and fixed
- Prioritize pacakges from 'atopile' over other packages

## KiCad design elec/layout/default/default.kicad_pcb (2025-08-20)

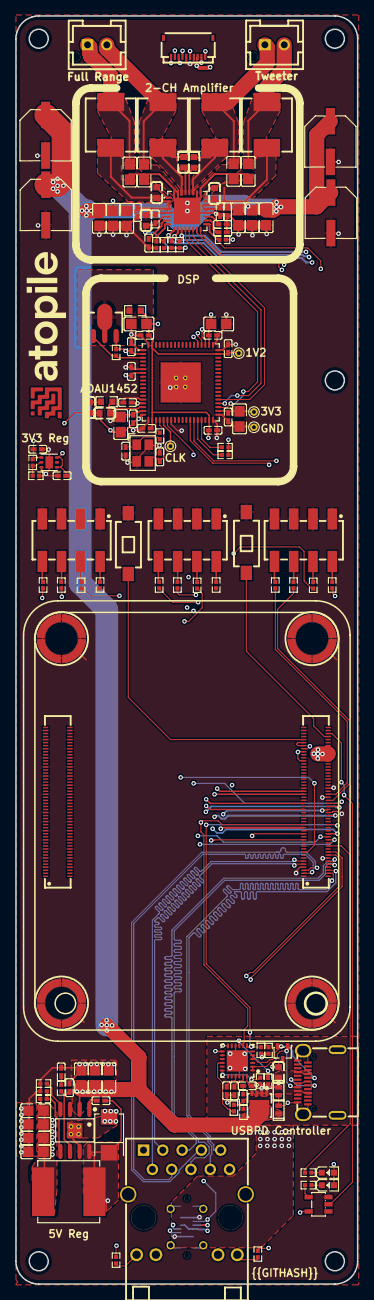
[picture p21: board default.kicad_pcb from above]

Board: 4 copper layers, 45.0 x 167.0 mm, 141 parts (1 on the bottom side), 106 nets.

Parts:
C1, C4, C19, C21, C22, C31, C32: 1µF ±10% 25V X5R; C0402
C2: 4.7µF ±10% 16V X5R; C0603
C3, C33, C38, C39, C40, C41, C42, C43, C44, C45, C46, C47, C53, C54, C55: 100nF ±10% 16V X7R; C0402
C5, C6, C9, C10: 470nF ±10% 50V X7R; C0603
C7, C8, C11, C12: 680nF ±10% 50V X7R; C0805
C13, C14, C15, C16, C17, C18, C34, C35, C36, C37: 10µF ±10% 25V X5R; C0805
C20: 100nF ±10% 50V X7R; C0402
C23: 4.7nF ±5% 50V X7R; C0402
C24: 20pF ±5% 50V C0G; C0402
C25, C26, C27: 10µF ±10% 50V X5R; C0805
C28, C29, C52, C60: 22µF ±20% 25V X5R; C0805
C30: 4.7µF ±10% 35V X5R; C0603
C48, C49: 15pF ±5% 50V C0G; C0402
C50: 5.6nF ±10% 50V X7R; C0603
C51: 150pF ±5% 50V C0G; C0603
C56, C57, C58, C59: CAP-SMD_BD6.3-L6.6-W6.6-FD
CN1, CN2: CONN-SMD_DF40C-100DS-0.4V-51
D1: LED0603-RD-YELLOW
D2: LED0603-RD
D3: SMB_L4.6-W3.6-LS5.3-RD
D4: SOT-323-3_L2.1-W1.3-P1.32-LS2.1-BR
D5, D6: DFN1610-2_L1.6-W1.0-P1.05-RD
FPC1: FPC-SMD_10P-P0.50_HDGC_0.5K-HX-10PWB
HDR1, HDR2, HDR3: HDR-SMD_8P-P2.54-V-M-R2-C4-LS7.4
L1, L2, L3, L4: 10µH ±20% 4.5A 68mΩ; IND-SMD_L7.3-W6.8
L5: IND-SMD_L8.0-W8.0_SWPA8040S
Q1: PDFN3333-8_L3.1-W3.2-P0.65-LS3.4-BL
Q2: SOT-89-3_L4.5-W2.5-P1.50-LS4.1-TR
R1, R15, R16: 4.7kΩ ±1% 62.5mW; R0402
R2, R3, R4, R5, R35, R37, R40, R41: 10kΩ ±1% 62.5mW; R0402
R6, R7: 2kΩ ±1% 62.5mW; R0402
R8, R9: 470Ω ±1% 62.5mW; R0402
R10: 23.7kΩ ±1% 62.5mW; R0402
R11, R12, R14, R17, R24, R25, R26, R27, R28, R29, R30, R31, R32, R33, R34: 1kΩ ±1% 62.5mW; R0402
R13: 162kΩ ±1% 62.5mW; R0402
R18: 100kΩ ±1% 62.5mW; R0402
R19: 22kΩ ±1% 62.5mW; R0402
R20, R21: 100Ω ±1% 62.5mW; R0402
R22: 0Ω 100mW; R0603
R23: 4.3kΩ ±1% 100mW; R0603
R36: 47kΩ ±1% 62.5mW; R0402
R38: 54.9kΩ ±1% 62.5mW; R0402
RJ1: RJ45-TH_HR911130A
SW1, SW2: SW-SMD_L6.0-W3.3-LS8.0
TP1, TP2, TP3, TP4: TestPoint_THTPad_D1.0mm_Drill0.5mm
U1: VQFN-32_L5.0-W5.0-P0.50-TL-EP
U2: SOT-23-5_L3.0-W1.7-P0.95-LS2.8-BR
U3, U4, U5, U6: SMD_BD5.6-D4.1
U7: SOIC-8_L5.0-W4.0-P1.27-LS6.0-BL-EP2.0
U20: QFN-24_L4.0-W4.0-P0.50-BL-EP2.8
U21, U22: CONN-TH_B02B-XASK-1-A-LF-SN
U23: USB-C-SMD_HC-TYPE-C-24P-VS9.3-5A-F1.1-04
U24: LFCSP-72_L10.0-W10.0-P0.50-LS10.2-BL-EP5.3
U25: WSON-6_L2.0-W2.0-P0.65-TL-EP
USB1: USB-C-SMD_TYC-324G
X1: CRYSTAL-SMD_4P-L3.2-W2.5-BL-2

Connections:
3v3_vcc: C2.1, C3.1, C22.1, C34.1, C35.1, C37.1, C38.1, C43.1, C44.1, C45.1, C46.1, C47.1, C50.2, C51.2, CN1.39, CN1.42, CN1.43, D1.2, D2.2, FPC1.6, Q2.1, R2.2, R3.2, R4.2, R5.2, R8.1, R9.1, R11.1, R15.2, R16.2, R24.1, R36.1, R40.2, R41.2, TP3.1, U1.6, U2.5, U24.2, U24.7, U24.15, U24.18, U24.38, U24.56, U25.1
5v_vcc: C21.1, C28.1, C29.1, C52.1, C60.1, CN1.57, CN1.58, CN1.59, CN1.60, CN1.61, CN1.62, FPC1.8, L5.2, R12.1, R38.1, U25.4, U25.6
20v_vcc: C13.1, C14.1, C15.1, C16.1, C17.1, C18.1, C25.1, C26.1, C27.1, C53.1, C54.1, C55.1, C56.1, C57.1, C58.1, C59.1, D6.1, Q1.5, Q1.6, Q1.7, Q1.8, Q1.9, R18.2, U1.3, U1.4, U1.21, U1.22, U7.2
A5: D4.1, U20.1, U20.2, U23.A5, USB1.A5
ADR: R1.1, U1.8
AVDD: C1.1, U1.19
B5: D4.2, U20.4, U20.5, U23.B5, USB1.B5
BOOT: C20.1, U7.1
BST_Aneg_N: C5.1, U1.29
BST_Apos_P: C6.1, U1.1
BST_Bneg_N: C9.1, U1.28
BST_Bpos_P: C10.1, U1.24
CLKOUT: TP1.1, U24.23
COMP: C24.1, R10.1, U7.6
DISCH: R14.2, U20.9
ETH_LED_LINK: CN1.93, RJ1.12
ETH_LED_SPEED: CN1.92, RJ1.13
ETH_P0_N: CN1.5, RJ1.P3
ETH_P0_P: CN1.6, RJ1.P2
ETH_P1_N: CN1.3, RJ1.P7
ETH_P1_P: CN1.2, RJ1.P4
ETH_P2_N: CN1.96, RJ1.P6
ETH_P2_P: CN1.95, RJ1.P5
ETH_P3_N: CN1.98, RJ1.P9
ETH_P3_P: CN1.99, RJ1.P8
GVDD: C4.1, U1.18
OUT_Aneg_N: C5.2, L1.1, U1.30
OUT_Apos_P: C6.2, L2.1, U1.2
OUT_Bneg_N: C9.2, L3.1, U1.27
OUT_Bpos_P: C10.2, L4.1, U1.23
PLLFILT: C51.1, R23.1, U24.16
RT_CLK: R13.1, U7.4
RX: CN1.73, R26.1
VBUS_EN_SNK: R19.2, U20.16
VBUS_VS_DISCH: R17.2, U20.18
VDRIVE: Q2.3, R24.2, U24.3
VREG_1V2-VCC: C31.2, U20.21
VREG_2V7-VCC: C32.2, U20.23
VR_DIG: C19.1, U1.7
XTALIN_MCLK: R21.1, U24.21
XTALOUT: C49.1, U24.22, X1.3
Y: R7.2, U2.4
activity_led-cathode: D1.1, R6.1
activity_led_resistor-pins[20]: CN1.90, R6.2
address_bit_0: R40.1, U24.33
address_bit_1: R41.1, U24.32
amp_fault: CN1.17, R2.1, U1.9
amp_i2s_sck: U1.13, U24.40
amp_i2s_sd: U1.14, U24.41
amp_i2s_ws: U1.12, U24.39
amp_mute: CN1.78, R3.1, U1.10
amp_pdn: CN1.15, R4.1, U1.17
amp_warn: CN1.80, R5.1, U1.11
boot_mode: CN1.54, SW1.1
bootstrap_capacitor-cathode: C20.2, D3.1, L5.1, U7.8
c1-net: C50.1, R23.2
cm5-anode-0: R8.2, RJ1.11
cm5-anode-1: R9.2, RJ1.14
cm5-cathode: D2.1, R7.1
collector: Q2.2, R22.1
compensation_capacitors[0]-net: C23.1, R10.2
debug_headers[0]-_2: HDR1.2, R11.2
debug_headers[0]-_4: HDR1.4, R12.2
debug_headers[0]-_6: HDR1.6, R25.2
debug_headers[0]-_8: HDR1.8, R26.2
debug_headers[1]-_2: HDR2.2, R27.2
debug_headers[1]-_4: HDR2.4, R28.2
debug_headers[1]-_6: HDR2.6, R29.2
debug_headers[1]-_8: HDR2.8, R30.2
debug_headers[2]-_2: HDR3.2, R31.2
debug_headers[2]-_4: HDR3.4, R32.2
debug_headers[2]-_6: HDR3.6, R33.2
debug_headers[2]-_8: HDR3.8, R34.2
dsp_reset_disable: CN1.87, U24.24
eth_sync_out: CN1.9, R28.1
feedback_divider-output-VDIV_OUTPUT-0: R35.1, R36.2, U25.2
feedback_divider-output-VDIV_OUTPUT-1: R37.1, R38.2, U7.5
footprint-net-2: C33.1, R20.2
gate: Q1.4, R18.1, R19.1, R20.1
gnd: C1.2, C2.2, C3.2, C4.2, C7.2, C8.2, C11.2, C12.2, C13.2, C14.2, C15.2, C16.2, C17.2, C18.2, C19.2, C21.2, C22.2, C23.2, C24.2, C25.2, C26.2, C27.2, C28.2, C29.2, C30.1, C31.1, C32.1, C34.2, C35.2, C36.2, C37.2, C38.2, C39.2, C40.2, C41.2, C42.2, C43.2, C44.2, C45.2, C46.2, C47.2, C48.2, C49.2, C52.2, C53.2, C54.2, C55.2, C56.2, C57.2, C58.2, C59.2, C60.2, CN1.1, CN1.4, CN1.7, CN1.11, CN1.16, CN1.21, CN1.26, CN1.30, CN1.33, CN1.37, CN1.49, CN1.65, CN1.68, CN1.71, CN1.74, CN1.79, CN1.84, CN1.89, CN1.94, CN1.97, CN1.100, CN2.4, CN2.7, CN2.10, CN2.13, CN2.16, CN2.19, CN2.22, CN2.28, CN2.31, CN2.34, CN2.37, CN2.40, CN2.43, CN2.46, CN2.49, CN2.52, CN2.55, CN2.58, CN2.61, CN2.64, CN2.67, CN2.70, CN2.73, CN2.82, CN2.85, CN2.88, CN2.91, CN2.94, CN2.97, D3.2, D4.3, D5.2, D6.2, FPC1.5, FPC1.7, HDR1.1, HDR1.3, HDR1.5, HDR1.7, HDR2.1, HDR2.3, HDR2.5, HDR2.7, HDR3.1, HDR3.3, HDR3.5, HDR3.7, R1.2, R13.2, R35.2, R37.2, RJ1.SHIELD0, RJ1.SHIELD1, SW1.2, SW2.2, TP2.1, U1.5, U1.20, U1.25, U1.26, U1.31, U1.32, U1.33, U2.3, U3.1, U3.2, U3.3, U3.4, U4.1, U4.2, U4.3, U4.4, U5.1, U5.2, U5.3, U5.4, U6.1, U6.2, U6.3, U6.4, U7.7, U7.9, U20.6, U20.10, U20.12, U20.13, U20.22, U20.25, U23.25, U23.26, U23.27, U23.28, U23.A1, U23.A12, U23.B1, U23.B12, U24.1, U24.6, U24.14, U24.17, U24.19, U24.25, U24.36, U24.37, U24.54, U24.55, U24.72, U24.73, U25.3, U25.7, USB1.1, USB1.2, USB1.3, USB1.4, USB1.A1, USB1.A12, USB1.B1, USB1.B12, X1.2, X1.4
i2c-SCL: CN1.83, R15.1, R30.1, U1.16, U20.7, U24.31
i2c-SCLK: CN1.18, R16.1, R29.1, U1.15, U20.8, U24.30
i2cs[1]-SCL: CN1.28, FPC1.9
i2cs[1]-SDA: CN1.29, FPC1.10
i2s_ins[0]-SCK: CN1.76, R34.1, U24.57
i2s_ins[0]-SD: CN1.88, R32.1, U24.59
i2s_ins[0]-WS: CN1.13, R33.1, U24.58
input-pins[94]: CN1.53, U2.2
led_data: CN1.77, FPC1.1
nOE: C48.1, R21.2, X1.1
nfc_interrupt: CN1.25, FPC1.3
nfc_reset: CN1.86, FPC1.4
power_1v8-VCC: CN1.44, CN1.45
power_button: CN1.46, SW2.1
power_digital-VCC: C36.1, C39.1, C40.1, C41.1, C42.1, R22.2, TP4.1, U24.20, U24.35, U24.53, U24.71
power_vbus-VCC: C30.2, C33.2, D5.1, Q1.1, Q1.2, Q1.3, R14.1, R17.1, U20.24, U23.A4, U23.A9, U23.B4, U23.B9, USB1.A4, USB1.A9, USB1.B4, USB1.B9
spkr_full_n: C7.1, L1.2, U21.2
spkr_full_p: C8.1, L2.2, U21.1
spkr_tweet_n: C11.1, L3.2, U22.1
spkr_tweet_p: C12.1, L4.2, U22.2
touch_interrupt: CN1.23, FPC1.2
uart-SCLK: CN1.75, R25.1
usb_connector-usb2-USB_D-0_N: USB1.A7, USB1.B7
usb_connector-usb2-USB_D-0_P: USB1.A6, USB1.B6
usb_connector-usb2-USB_D-1_N: U23.A7, U23.B7
usb_connector-usb2-USB_D-1_P: U23.A6, U23.B6

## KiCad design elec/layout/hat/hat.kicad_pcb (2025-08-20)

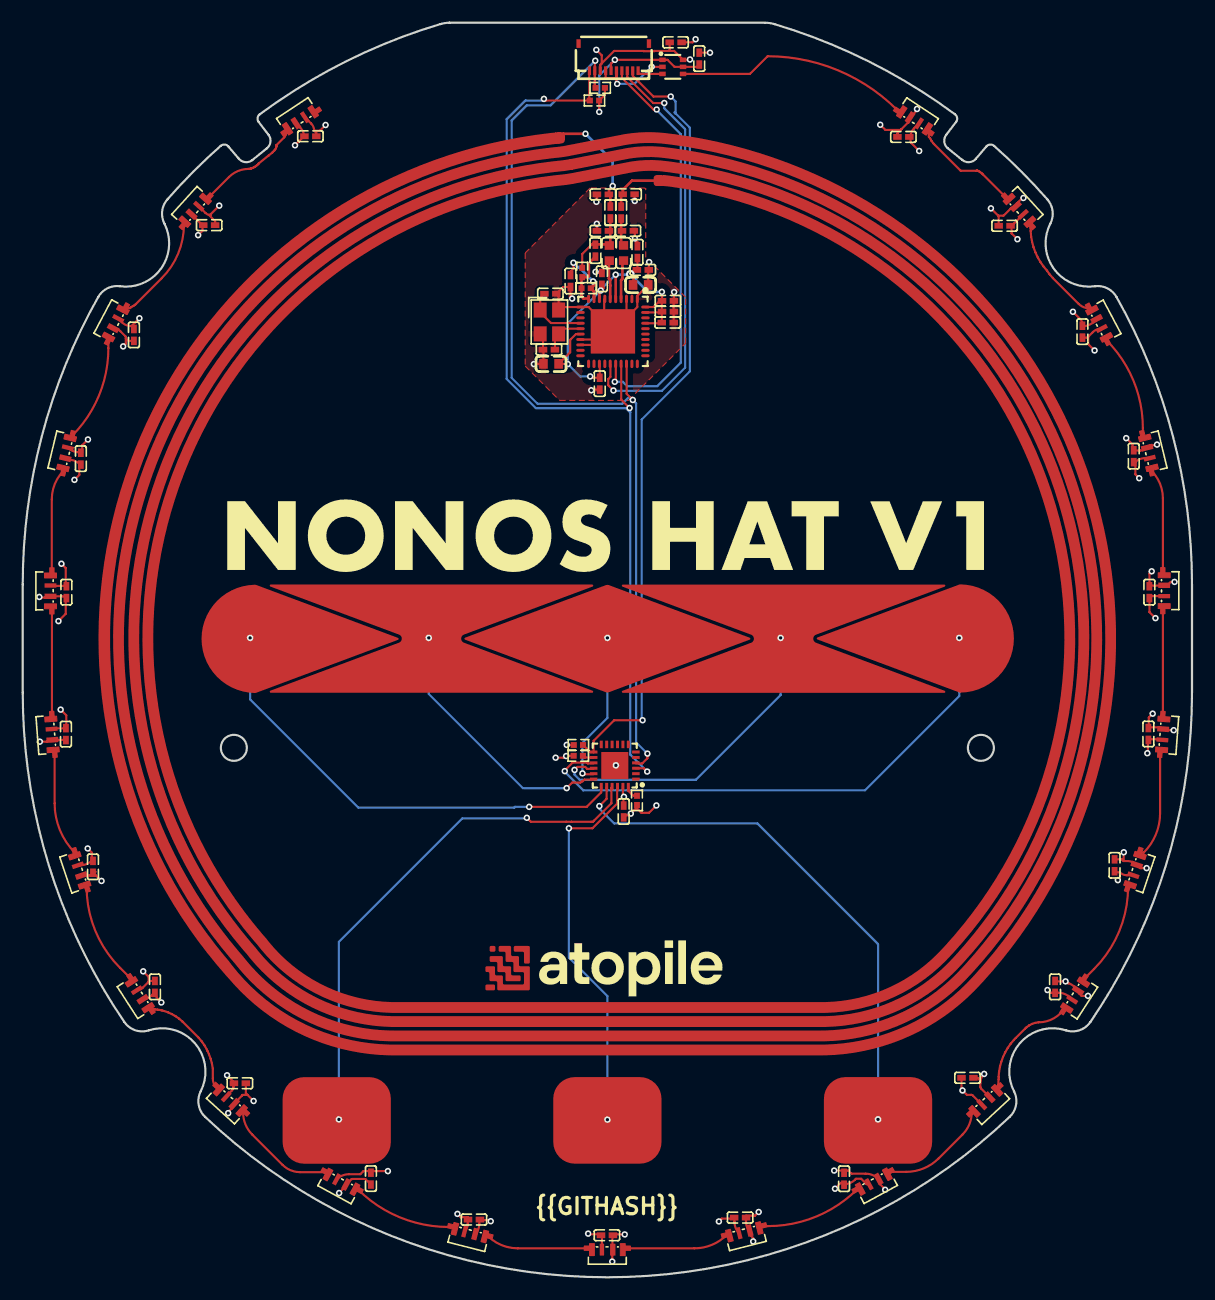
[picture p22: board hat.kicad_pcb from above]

Board: 4 copper layers, 108.0 x 115.9 mm, 83 parts (0 on the bottom side), 52 nets.

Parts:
ANT1: hat-button-antenna
C1, C2, C3, C4, C5, C6, C7, C8, C9, C10, C11, C12, C14, C16, C17, C18, C19, C20, C21, C22, C23, C24, C25, C26, C27, C28, C29, C30, C34, C36, C37, C38, C39, C42, C43, C44, C45: 100nF ±10% 16V X7R; C0402
C13, C15: 100pF ±5% 50V C0G; C0402
C31, C32: 20pF ±5% 50V C0G; C0402
C33, C35: 10µF ±20% 6.3V X5R; C0603
C40, C41: 220pF ±10% 50V X7R; C0402
FPC1: FPC-SMD_10P-P0.50_HDGC_0.5K-HX-10PWB
L1, L2: IND-SMD_L1.6-W0.8-1
R1, R2, R6, R7: 10kΩ ±1% 62.5mW; R0402
R3: 100kΩ ±1% 62.5mW; R0402
R4, R5: 1kΩ ±1% 62.5mW; R0402
U1, U2, U3, U4, U5, U6, U8, U9, U10, U11, U12, U13, U14, U15, U16, U17, U18, U19, U20, U21, U22, U23, U24: LED-SMD_4P-L3.5-W1.6_SK6805SIDE-G-001
U7: QFN-40_L6.0-W6.0-P0.50-BL-EP4.1
U25: QFN-24_L4.0-W4.0-P0.50-BL-EP2.5
U26: SC-70-6_L2.2-W1.3-P0.65-LS2.1-BR
X1: CRYSTAL-SMD_4P-L3.2-W2.5-BL

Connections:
A: FPC1.10, U26.3
ADDR_COMM: R3.1, U25.14
B: U2.4, U26.4
GND: C1.2, C2.2, C3.2, C4.2, C5.2, C6.2, C7.2, C8.2, C9.2, C10.2, C11.2, C13.2, C15.2, C17.2, C18.2, C19.2, C20.2, C21.2, C22.2, C23.2, C24.2, C25.2, C26.2, C27.2, C28.2, C29.2, C30.2, C31.2, C32.2, C33.2, C34.2, C35.2, C36.2, C37.2, C38.2, C39.2, C40.2, C41.2, C42.2, C43.2, C44.2, C45.2, FPC1.4, FPC1.6, R3.2, R7.2, U1.2, U2.2, U3.2, U4.2, U5.2, U6.2, U7.1, U7.3, U7.7, U7.11, U7.17, U7.18, U7.41, U8.2, U9.2, U10.2, U11.2, U12.2, U13.2, U14.2, U15.2, U16.2, U17.2, U18.2, U19.2, U20.2, U21.2, U22.2, U23.2, U24.2, U25.25, U26.2, X1.2, X1.4
OSCIN: C31.1, U7.14, X1.1
OSCOUT: C32.1, U7.15, X1.3
P70_IRQ: FPC1.8, U7.25
RESET: R7.1, U25.24
RSTOUT_N: FPC1.7, U7.26
RX: C12.2, R4.2, R5.2, U7.10
SCL: FPC1.2, R2.1, U7.28, U25.4
SDA: FPC1.1, R1.1, U7.27, U25.3
TX1: L1.2, U7.4
TX2: L2.2, U7.6
antenna_N: ANT1.9, C15.1, C16.2
antenna_P: ANT1.10, C13.1, C14.2
data_out-DIN: U3.4, U24.1
leds[1]-data_in-DIN: U2.1, U13.4
leds[2]-data_in-DIN: U13.1, U17.4
leds[3]-data_in-DIN: U17.1, U18.4
leds[4]-data_in-DIN: U18.1, U19.4
leds[5]-data_in-DIN: U19.1, U20.4
leds[6]-data_in-DIN: U20.1, U21.4
leds[7]-data_in-DIN: U21.1, U22.4
leds[8]-data_in-DIN: U22.1, U23.4
leds[9]-data_in-DIN: U23.1, U24.4
leds[11]-data_in-DIN: U3.1, U4.4
leds[12]-data_in-DIN: U4.1, U5.4
leds[13]-data_in-DIN: U5.1, U6.4
leds[14]-data_in-DIN: U1.4, U6.1
leds[15]-data_in-DIN: U1.1, U8.4
leds[16]-data_in-DIN: U8.1, U9.4
leds[17]-data_in-DIN: U9.1, U10.4
leds[18]-data_in-DIN: U10.1, U11.4
leds[19]-data_in-DIN: U11.1, U12.4
leds[20]-data_in-DIN: U12.1, U14.4
leds[21]-data_in-DIN: U14.1, U15.4
leds[22]-data_in-DIN: U15.1, U16.4
nALERT_nBC_IRQ: FPC1.9, R6.1, U25.13
next_button: ANT1.3, U25.20
play_button: ANT1.2, U25.22
power-VCC: C29.1, C30.1, C33.1, C34.1, C35.1, C36.1, C37.1, C38.1, C39.1, C43.1, C44.1, FPC1.5, R1.2, R2.2, R6.2, U7.5, U7.8, U7.16, U7.23, U7.37, U7.39, U7.40, U25.23, U26.1, U26.5
power_b-VCC: C1.1, C2.1, C3.1, C4.1, C5.1, C6.1, C7.1, C8.1, C9.1, C10.1, C11.1, C17.1, C18.1, C19.1, C20.1, C21.1, C22.1, C23.1, C24.1, C25.1, C26.1, C27.1, C28.1, C45.1, FPC1.3, U1.3, U2.3, U3.3, U4.3, U5.3, U6.3, U8.3, U9.3, U10.3, U11.3, U12.3, U13.3, U14.3, U15.3, U16.3, U17.3, U18.3, U19.3, U20.3, U21.3, U22.3, U23.3, U24.3, U26.6
power_vmid-VCC: C42.1, R5.1, U7.9
prev_button: ANT1.1, U25.21
slider[0]: ANT1.4, U25.19
slider[1]: ANT1.5, U25.18
slider[2]: ANT1.6, U25.17
slider[3]: ANT1.7, U25.16
slider[4]: ANT1.8, U25.15
tx_1_mid: C14.1, C40.1, L1.1
tx_2_mid: C12.1, C16.1, C41.1, L2.1, R4.1

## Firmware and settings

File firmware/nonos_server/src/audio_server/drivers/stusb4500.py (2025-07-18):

#!/usr/bin/env python3
"""STUSB4500 USB Type-C Power Delivery Controller Driver.

https://github.com/timkruse/stusb4500/tree/master/sw

USB Type C Evaluation Board based on STUSB4500 by STM.

This project implements the USB Type C connector based on the STM's STUSB4500 USB Power Delivery controller.
All signals are either routed to the dedicated USB connector or to an external connector to access signals such as I2C
which is the config interface of the STUSB4500.
The power lines are controlled by FETs to suit the 100W specification of USB-C.

Original 2019 by Tim Kruse
Modified 2023 by Patrick Wallner aka MCPat

Modifications:
1. Adapted code to run with Python3
2. Adapted NVM to work with new power supply from RPi5 (5V 5A)
3. Uncommented some comments in set_pdo
4. Bugfix in set_pdo_variable

GUI for NVM can be found at https://github.com/usb-c/STUSB4500/blob/master/GUI/App/STSW-STUSB002%20v1.0.8.zip
"""

import subprocess
from dataclasses import dataclass
from time import sleep

from smbus2 import SMBus


@dataclass
class Version:
    """USB Type-C and USB PD revision information."""

    typec_rev: int
    usbpd_rev: int

    def __str__(self):
        return (
            f"Version(typec_rev={hex(self.typec_rev)}, usbpd_rev={hex(self.usbpd_rev)})"
        )

    __repr__ = __str__


@dataclass
class PortStatus:
    """Port connection status information."""

    stateChanged: int
    attachedDevice: int
    lowPowerStandby: int
    powerMode: int
    dataMode: int
    attached: int

    def __str__(self):
        attachedDeviceAsString = [
            "None",
            "Sink",
            "Source",
            "Debug Accessory",
            "Audio Accessory",
            "Power Accessory",
        ]
        return (
            f"PortStatus(stateChanged={'True' if self.stateChanged == 1 else 'False'}, "
            f"attachedDevice={attachedDeviceAsString[self.attachedDevice] if (self.attachedDevice >= 0 and self.attachedDevice <= 5) else f'undefined({self.attachedDevice})'}, "
            f"lowPowerStandby={'standby mode' if self.lowPowerStandby == 1 else 'normal mode'}, "
            f"powerMode={'Source' if self.powerMode == 1 else 'Sink'}, "
            f"dataMode={'DFP' if self.dataMode == 1 else 'UFP'}, "
            f"attached={'True' if self.attached == 1 else 'False'})"
        )

    __repr__ = __str__


@dataclass
class PDO_Contract:
    """Active Power Delivery Object contract number."""

    num: int


# Supply type strings used by PDO classes
supplyStr = ["Fixed", "Variable", "Battery"]


@dataclass
class PdoSinkFix:
    """Fixed voltage Power Delivery Object for sink."""

    current: int
    voltage: int
    fastRoleReqCur: int
    dualRoleData: int
    usbCommunicationsCapable: int
    unconstrainedPower: int
    higherCapability: int
    dualRolePower: int
    supply: int
    raw: int

    def __str__(self):
        return (
            f"PdoSink(voltage={self.voltage / 20.0}V, "
            f"current={self.current / 100.0}A, "
            f"fastRoleReqCur={self.fastRoleReqCur}, "
            f"dualRoleData={self.dualRoleData}, "
            f"usbCommunicationsCapable={self.usbCommunicationsCapable}, "
            f"unconstrainedPower={self.unconstrainedPower}, "
            f"higherCapability={self.higherCapability}, "
            f"dualRolePower={self.dualRolePower}, "
            f"supply={supplyStr[self.supply] if self.supply >= 0 and self.supply < 3 else 'Undefined'}, "
            f"raw=0x{self.raw:08x})"
        )

    __repr__ = __str__


@dataclass
class PdoSinkVar:
    """Variable voltage Power Delivery Object for sink."""

    min_voltage: int
    max_voltage: int
    current: int
    supply: int
    raw: int

    def __str__(self):
        return (
            f"PdoSink(voltage=[{self.min_voltage / 20.0}V-{self.max_voltage / 20.0}V], "
            f"current={self.current / 100.0}A, "
            f"supply={supplyStr[self.supply] if self.supply >= 0 and self.supply < 3 else 'Undefined'}, "
            f"raw=0x{self.raw:08x})"
        )

    __repr__ = __str__


@dataclass
class PdoSinkBat:
    """Battery Power Delivery Object for sink."""

    min_voltage: int
    max_voltage: int
    power: int
    supply: int
    raw: int

    def __str__(self):
        return (
            f"PdoSink(voltage=[{self.min_voltage / 20.0}V-{self.max_voltage / 20.0}V], "
            f"power={self.power}W, "
            f"supply={supplyStr[self.supply] if self.supply >= 0 and self.supply < 3 else 'Undefined'}, "
            f"raw=0x{self.raw:08x})"
        )

    __repr__ = __str__


@dataclass
class Rdo:
    """Requested Data Object containing negotiated power parameters."""

    voltage: float
    current: int
    maxCurrent: int
    unchunkedMess_sup: int
    usbSuspend: int
    usbComCap: int
    capaMismatch: int
    giveBack: int
    objectPos: int
    raw: int

    def __str__(self):
        return (
            f"RDO(voltage={self.voltage}V, "
            f"current={self.current / 100.0}A, "
            f"maxCurrent={self.maxCurrent / 100.0}A, "
            f"unchunkedMess_sup={self.unchunkedMess_sup}, "
            f"usbSuspend={self.usbSuspend}, "
            f"usbComCap={self.usbComCap}, "
            f"capaMismatch={self.capaMismatch}, "
            f"giveBack={self.giveBack}, "
            f"objectPos={self.objectPos}, "
            f"raw=0x{self.raw:08x})"
        )

    __repr__ = __str__


@dataclass
class Vbus:
    """VBUS control and discharge configuration."""

    discharge_0v: int
    discharge_trans: int
    vbus_discharge: bool
    vsrc_discharge: bool
    sink_vbus_en: bool

    def __str__(self):
        return (
            f"VBUS(discharge_time_transition={self.discharge_trans * 24}ms, "
            f"discharge_to_0V={self.discharge_0v * 84}ms, "
            f"vbus_discharge={'Enabled' if self.vbus_discharge else 'Disabled'}, "
            f"vsrc_discharge={'Enabled' if self.vsrc_discharge else 'Disabled'}, "
            f"sink_vbus_en={'Enabled' if self.sink_vbus_en else 'Disabled'})"
        )

    __repr__ = __str__


# Default NVM values programmed by factory for SparkFun board
nvm_factory_defaults_sparkfun = {
    0: [0x00, 0x00, 0x60, 0x55, 0x01, 0x8A, 0x00, 0x00],
    1: [0x10, 0x40, 0x9C, 0x1C, 0xFF, 0x01, 0x3C, 0xDF],
    2: [0x02, 0x40, 0x0F, 0x00, 0x32, 0x00, 0xFC, 0xF1],
    3: [0x00, 0x19, 0x56, 0xAF, 0xF5, 0x35, 0x5F, 0x00],
    4: [0x00, 0x4B, 0x90, 0x21, 0x43, 0x00, 0x40, 0xFB],
}

# NVM configuration for Raspberry Pi 5 power requirements (5V up to 5A)
nvm_pi5 = {
    0: [0x00, 0x00, 0x60, 0x55, 0x01, 0x8A, 0x00, 0x00],
    1: [0x10, 0x40, 0x9D, 0x1C, 0xF0, 0x01, 0x38, 0xDF],
    2: [0xC2, 0x40, 0x0F, 0x01, 0x32, 0x00, 0xFC, 0xF1],
    3: [0x00, 0x19, 0x56, 0x5F, 0x5B, 0xF5, 0x55, 0x00],
    4: [0x00, 0x19, 0x64, 0x20, 0x43, 0x00, 0x40, 0xFB],
}

#  5V 1.5A
# 20V Flex 5A
# 20V 3A
# TO change PD settings use STSW-STUSB002. See https://github.com/usb-c/STUSB4500.
nvm_custom = {
    0: [0x00, 0x00, 0xB0, 0xAB, 0x00, 0x45, 0x00, 0x00],
    1: [0x10, 0x40, 0x9C, 0x1C, 0xFF, 0x01, 0x3C, 0xDF],
    2: [0x02, 0x40, 0x0F, 0x00, 0x32, 0x00, 0xFC, 0xF1],
    3: [0x00, 0x19, 0x56, 0xAF, 0xF0, 0xB5, 0x5F, 0x00],
    4: [0x00, 0x64, 0x90, 0xD1, 0x47, 0x00, 0x40, 0xFB],
}


class STUSB4500:
    """Driver for STUSB4500 USB Type-C Power Delivery Controller.

    This class provides methods to interact with the STUSB4500 chip via I2C,
    including reading status, configuring PDOs, and managing NVM.

    Args:
        i2c_bus: I2C bus number (default: 0).
        i2c_addr: I2C address of the chip (default: 0x28).
        reset_pin: GPIO pin number for hardware reset (default: 4).
    """

    def __init__(
        self, i2c_bus: SMBus, i2c_addr: int = 0x28, reset_pin: int | None = None
    ):
        self.addr = i2c_addr
        self.bus = i2c_bus
        self.reset_pin = reset_pin

    def _set_gpio_output(self, gpio: int, high: bool):
        """Set GPIO output state using pinctrl."""
        subprocess.check_output(["pinctrl", "set", str(gpio), "op"])
        subprocess.check_output(
            ["pinctrl", "set", str(gpio), f"d{'h' if high else 'l'}"]
        )

    def hard_reset(self):
        """Perform a hardware reset of the STUSB4500 chip using GPIO."""
        if self.reset_pin is None:
            raise ValueError("Reset pin is not set")

        self._set_gpio_output(self.reset_pin, True)
        sleep(0.2)
        self._set_gpio_output(self.reset_pin, False)

    def version(self):
        """Read Type-C and USB PD revision information from the chip.

        Returns:
            Version: Object containing typec_rev and usbpd_rev.
        """
        BCD_TYPEC_REV_LOW = self.bus.read_byte_data(self.addr, 0x06)
        BCD_TYPEC_REV_HIGH = self.bus.read_byte_data(self.addr, 0x07)
        typec_rev = BCD_TYPEC_REV_HIGH << 8 | BCD_TYPEC_REV_LOW

        BCD_USBPD_REV_LOW = self.bus.read_byte_data(self.addr, 0x08)
        BCD_USBPD_REV_HIGH = self.bus.read_byte_data(self.addr, 0x09)
        usbpd_rev = BCD_USBPD_REV_HIGH << 8 | BCD_USBPD_REV_LOW

        return Version(typec_rev=typec_rev, usbpd_rev=usbpd_rev)

    def port_status(self):
        """Read the current status of the USB Type-C port.

        Returns:
            PortStatus: Object containing port connection and power status.
        """
        PORT_STATUS_0 = self.bus.read_byte_data(self.addr, 0x0D)
        PORT_STATUS_1 = self.bus.read_byte_data(self.addr, 0x0E)

        return PortStatus(
            stateChanged=PORT_STATUS_0 & 0x01,
            attachedDevice=PORT_STATUS_1 >> 5 & 0x07,
            lowPowerStandby=PORT_STATUS_1 >> 4 & 0x01,
            powerMode=PORT_STATUS_1 >> 3 & 0x01,
            dataMode=PORT_STATUS_1 >> 2 & 0x01,
            attached=PORT_STATUS_1 & 0x01,
        )

    def active_contract(self):
        """Read the currently active PDO contract number.

        Returns:
            PDO_Contract: Object containing the active PDO number (0-3).
        """
        DPM_PDO_NUMB = self.bus.read_byte_data(self.addr, 0x70)
        return PDO_Contract(num=DPM_PDO_NUMB & 3)

    def set_active_contract(self, newValue):
        """Force the use of a specific PDO contract.

        The STUSB4500 offers 3 PDO contracts and changes take effect after a soft reset.

        Args:
            newValue: PDO contract number (0-3).
        """
        if newValue >= 0 and newValue < 4:
            return self.bus.write_byte_data(self.addr, 0x70, newValue)

    def read_pdo(self):
        """Read all currently configured PDOs from the chip.

        Note: REQ_SRC_CURRENT == unconstrainedPower

        Returns:
            dict: Dictionary with PDO numbers (1-3) as keys and PDO objects as values.
        """
        bvalues = []  # byte values
        for reg in range(0x85, 0x91):
            bvalues.append(self.bus.read_byte_data(self.addr, reg))

        pdo = {}
        for i in range(0, 3):
            reg = (
                bvalues[i * 4 + 3] << 24
                | bvalues[i * 4 + 2] << 16
                | bvalues[i * 4 + 1] << 8
                | bvalues[i * 4]
            )
            supply = reg >> 30 & 0x3
            if supply == 0:  #  fixed
                pdo[i + 1] = PdoSinkFix(
                    supply=supply,
                    dualRolePower=reg >> 29 & 0x1,
                    higherCapability=reg >> 28 & 0x1,
                    unconstrainedPower=reg >> 27 & 0x1,
                    usbCommunicationsCapable=reg >> 26 & 0x1,
                    dualRoleData=reg >> 25 & 0x1,
                    fastRoleReqCur=reg >> 23 & 0x3,
                    voltage=reg >> 10 & 0x3FF,
                    current=reg & 0x3FF,
                    raw=reg,
                )
            elif supply == 1:  # variable
                pdo[i + 1] = PdoSinkVar(
                    supply=supply,
                    max_voltage=reg >> 20 & 0x3FF,
                    min_voltage=reg >> 10 & 0x3FF,
                    current=reg & 0x3FF,
                    raw=reg,
                )
            elif supply == 2:  # battery
                pdo[i + 1] = PdoSinkBat(
                    supply=supply,
                    max_voltage=reg >> 20 & 0x3FF,
                    min_voltage=reg >> 10 & 0x3FF,
                    power=reg & 0x3FF,
                    raw=reg,
                )
        return pdo

    def print_pdo(self):
        """Read and print all Power Data Objects."""
        for k, v in self.read_pdo().items():
            print("PDO#" + str(k) + ": ", v)

    def read_rdo(self):
        """Read the Requested Data Object (RDO).

        Returns:
            Rdo: Object containing the negotiated power parameters.
        """
        bvalues = []  # byte values
        for reg in range(0x91, 0x95):
            bvalues.append(self.bus.read_byte_data(self.addr, reg))

        requested_voltage = self.bus.read_byte_data(self.addr, 0x21)  # *100mV
        requested_voltage /= 10.0  # I want it in Volt not milli volt

        reg = bvalues[3] << 24 | bvalues[2] << 16 | bvalues[1] << 8 | bvalues[0]
        return Rdo(
            voltage=requested_voltage,
            objectPos=reg >> 28 & 0x7,
            giveBack=reg >> 27 & 0x1,
            capaMismatch=reg >> 26 & 0x1,
            usbComCap=reg >> 25 & 0x1,
            usbSuspend=reg >> 24 & 0x1,
            unchunkedMess_sup=reg >> 23 & 0x1,
            current=reg >> 10 & 0x3FF,
            maxCurrent=reg & 0x3FF,
            raw=reg,
        )

    def reset(self):
        """Perform a software reset of the STUSB4500.

        Uses RESET_CTRL Register @0x23 bit 0 = {1 := reset, 0 := no reset}.
        """
        RESET_CTRL = self.bus.read_byte_data(self.addr, 0x23)
        self.bus.write_byte_data(self.addr, 0x23, RESET_CTRL | 0x01)
        sleep(0.25)
        self.bus.write_byte_data(self.addr, 0x23, RESET_CTRL & ~0x01)

    def set_pdo(self, num, volt, current):
        """Set a fixed voltage PDO configuration.

        Args:
            num: PDO number to configure (1-3).
            volt: Desired voltage in mV.
            current: Desired current in mA.
        """
        if num > 0 and num < 4:
            reg32 = (int(current / 10) & 0x3FF) | int(volt / 50) << 10 | (1 << 29)
            self.bus.write_byte_data(self.addr, 0x85 + (num - 1) * 4, reg32 & 0xFF)
            self.bus.write_byte_data(
                self.addr, 0x86 + (num - 1) * 4, (reg32 >> 8) & 0xFF
            )
            self.bus.write_byte_data(
                self.addr, 0x87 + (num - 1) * 4, (reg32 >> 16) & 0xFF
            )
            self.bus.write_byte_data(
                self.addr, 0x88 + (num - 1) * 4, (reg32 >> 24) & 0xFF
            )
        else:
            print(num, " is no valid pdo!")

    def set_pdo_variable(self, pdo_num, current, min_voltage, max_voltage):
        """Configure a PDO with variable voltage range.

        Args:
            pdo_num: PDO number to configure (2-3, PDO1 cannot be variable).
            current: Desired current in mA.
            min_voltage: Minimum voltage in mV (5000-20000).
            max_voltage: Maximum voltage in mV (5000-20000).
        """
        if pdo_num > 1 and pdo_num <= 3:
            if (
                min_voltage >= 5000
                and min_voltage <= 20000
                and max_voltage >= 5000
                and max_voltage <= 20000
                and min_voltage <= max_voltage
            ):
                reg32 = 1 << 30  # variable supply
                reg32 |= int(current / 10)
                reg32 |= int(min_voltage / 50) << 10  # min voltage
                reg32 |= int(max_voltage / 50) << 20  # max voltage

                self.bus.write_byte_data(
                    self.addr, 0x85 + (pdo_num - 1) * 4, reg32 & 0xFF
                )
                self.bus.write_byte_data(
                    self.addr, 0x86 + (pdo_num - 1) * 4, (reg32 >> 8) & 0xFF
                )
                self.bus.write_byte_data(
                    self.addr, 0x87 + (pdo_num - 1) * 4, (reg32 >> 16) & 0xFF
                )
                self.bus.write_byte_data(
                    self.addr, 0x88 + (pdo_num - 1) * 4, (reg32 >> 24) & 0xFF
                )
        elif pdo_num == 1:
            print("PDO#1 cannot have a variable supply")

    def nvm_lock(self, lock):
        """Lock or unlock the internal NVM registers.

        Args:
            lock: True to lock, False to unlock.
        """
        if lock is False:
            self.bus.write_byte_data(self.addr, 0x95, 0x47)
        else:
            self.bus.write_byte_data(self.addr, 0x95, 0x00)

    def nvm_dump(self):
        """Dump the contents of the NVM (Non-Volatile Memory).

        Factory NVM dump reference:
            00 00 b0 aa 00 45 00 00 (0xc0-0xc7 hidden)
            10 40 9c 1c ff 01 3c df (0xc8-0xcf)
            02 40 0f 00 32 00 fc f1 (0xd0-0xd7)
            00 19 56 af f5 35 5f 00 (0xd8-0xdf)
            00 4b 90 21 43 00 40 fb (0xe0-0xe7)
        """
        self.nvm_lock(False)  # unlock NVM

        def nvm_wait_for_execution():
            while True:
                reg8 = self.bus.read_byte_data(self.addr, 0x96)
                if reg8 & 0x10 == 0x00:
                    break

        sector_data = []
        for num_sector in range(0, 5):
            # send command opcode READ(0x00) to FTP_CTRL_1(0x97)
            self.bus.write_byte_data(self.addr, 0x97, 0 & 0x07)
            # execute command
            self.bus.write_byte_data(
                self.addr, 0x96, (num_sector & 0x07) | 0x80 | 0x40 | 0x10
            )
            nvm_wait_for_execution()
            # read 8 bytes that are copied from nvm to 0x53-0x5a
            sector = []
            for i in range(0, 8):
                sector.append(self.bus.read_byte_data(self.addr, 0x53 + i))
            sector_data.append(sector)
        self.nvm_lock(True)  # lock NVM

        # nicely print out the values
        data = dict(enumerate(sector_data))
        return data

    # Write procedure:
    # Enter Write mode:
    # 1. PASSWORD_REG(0x95) <= PASSWORD(0x47) to unlock flash
    # 2. RW_BUFFER(0x53) <= 0 if partial erasing sectors
    # 3. CTRL_0(0x96) <= PWR | RST_N to soft reset chip and power on
    # 4. CTRL_1(0x97) <= SECTORS_TOBE_ERASED_MASK << 3 | WRITE_SER to send erase command for the specified sectors (1 hot encoded)
    # 5. CTRL_0(0x96) <= PWR | RST_N | REQ to commit command in CTRL_1
    # 6. Wait until REQ bit in CTRL_0 is cleared
    # 7. CTRL_1(0x97) <= SOFT_PROG_SECTOR
    # 8. CTRL_0(0x96) <= PWR | RST_N | REQ to commit command in CTRL_1
    # 9. Wait until REQ bit in CTRL_0 is cleared
    # 10. CTRL_1(0x97) <= ERASE_SECTOR
    # 11. CTRL_0(0x96) <= PWR | RST_N | REQ to commit command in CTRL_1
    # 12. Wait until REQ bit in CTRL_0 is cleared
    # Write Sector:
    # 1. Write sector data into RW_BUFFER(0x53-0x5A)
    # 2. CTRL_0(0x96) <= PWR | RST_N
    # 3. CTRL_1(0x97) <= WRITE_PLR
    # 4. CTRL_0(0x96) <= PWR | RST_N | REQ to commit command in CTRL_1
    # 5. Wait until REQ bit in CTRL_0 is cleared
    # 6. CTRL_1(0x97) <= PROG_SECTOR
    # 7. CTRL_0(0x96) <= PWR | RST_N | REQ | SECTOR to commit command in CTRL_1
    # 8. Wait until REQ bit in CTRL_0 is cleared
    # Exit Programming mode:
    # 1. CTRL_0(0x96) <= RST_N
    # 2. CTRL_1(0x97) <= 0
    # 3. PASSWD(0x95) <= 0

    def nvm_write(self, sector_data):
        """Write data into NVM (Non-Volatile Memory).

        Args:
            sector_data: Dictionary where keys are sector numbers (0-4) and values are lists of 8 bytes.

        Note:
            Requires a hard reset to take effect.
        """
        pwr = 0x80
        rst_n = 0x40
        req = 0x10

        def nvm_wait_for_execution():
            while True:
                reg8 = self.bus.read_byte_data(self.addr, 0x96)
                if reg8 & 0x10 == 0x00:
                    break

        section_mask = 0
        for k, v in sector_data.items():
            if k >= 0 and k <= 4:
                if len(v) == 8:
                    section_mask |= 1 << k
                else:
                    print(f"New sector data has to many bytes (sector: {k})")
                    return
            else:
                print(f"Invalid sector {k}")
                return

        self.nvm_lock(False)
        # Erase specified sectors to be able to program them
        # self.bus.write_byte_data(self.addr, 0x53, 0x00)
        # self.bus.write_byte_data(self.addr, 0x96, pwr | rst_n)
        self.bus.write_byte_data(
            self.addr, 0x97, section_mask << 3 | 0x02
        )  # WRITE_SER opcode
        self.bus.write_byte_data(self.addr, 0x96, pwr | rst_n | req)
        nvm_wait_for_execution()
        self.bus.write_byte_data(self.addr, 0x97, 0x07)  # Soft_prog_sector opcode
        self.bus.write_byte_data(self.addr, 0x96, pwr | rst_n | req)
        nvm_wait_for_execution()
        self.bus.write_byte_data(self.addr, 0x97, 0x05)  # erase_sector opcode
        self.bus.write_byte_data(self.addr, 0x96, pwr | rst_n | req)
        nvm_wait_for_execution()
        # Write data to sectors
        for k, v in sector_data.items():
            # write new data into rw_bufer@0x53
            rw_buffer = 0x53
            for byte in v:
                self.bus.write_byte_data(self.addr, rw_buffer, byte)
                rw_buffer += 1
            self.bus.write_byte_data(self.addr, 0x97, 0x01)  # WRITE_PLR opcode
            self.bus.write_byte_data(self.addr, 0x96, pwr | rst_n | req)
            nvm_wait_for_execution()
            self.bus.write_byte_data(self.addr, 0x97, 0x06)  # PROG_SECTOR opcode
            self.bus.write_byte_data(self.addr, 0x96, pwr | rst_n | req | k)
            nvm_wait_for_execution()
        # Exit programming mode
        self.bus.write_byte_data(self.addr, 0x96, rst_n)
        self.bus.write_byte_data(self.addr, 0x97, 0)
        self.nvm_lock(True)

    def vbus_ctrl(self):
        """Read VBUS control and discharge configuration.
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

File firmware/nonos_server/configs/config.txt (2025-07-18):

# For more options and information see
# http://rptl.io/configtxt
# Some settings may impact device functionality. See link above for details

# Uncomment some or all of these to enable the optional hardware interfaces
dtparam=i2c_arm=on
dtparam=i2c_vc=on
dtparam=i2c1_on
#dtoverlay=hat
#dtparam=i2s=on
#dtparam=spi=on

# Enable audio (loads snd_bcm2835)
#dtparam=audio=on

# Additional overlays and parameters are documented
# /boot/firmware/overlays/README

# Automatically load overlays for detected cameras
camera_auto_detect=1

# Automatically load overlays for detected DSI displays
display_auto_detect=1

# Automatically load initramfs files, if found
auto_initramfs=1

# Enable DRM VC4 V3D driver
dtoverlay=vc4-kms-v3d
max_framebuffers=2

# Don't have the firmware create an initial video= setting in cmdline.txt.
# Use the kernel's default instead.
disable_fw_kms_setup=1

# Run in 64-bit mode
arm_64bit=1

# Disable compensation for displays with overscan
disable_overscan=1

# Run as fast as firmware / board allows
arm_boost=1

[cm4]
# Enable host mode on the 2711 built-in XHCI USB controller.
# This line should be removed if the legacy DWC2 controller is required
# (e.g. for USB device mode) or if USB support is not required.
otg_mode=1

[cm5]
dtoverlay=dwc2,dr_mode=host

[all]

dtoverlay=i2s-mmap
dtoverlay=googlevoicehat-soundcard
dtparam=i2s=on

hdmi_drive=1
hdmi_ignore_edid_audio=1
dtoverlay=vc4-kms-v3d,noaudio


#dtoverlay=hat
#dtparam=ant2

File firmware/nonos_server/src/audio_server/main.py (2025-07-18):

import signal
import socket
import threading

import smbus2
import typer

from audio_server.drivers.adau1452 import ADAU1452
from audio_server.drivers.cap1188 import CAP1188, Button, Buttons
from audio_server.drivers.stusb4500 import STUSB4500
from audio_server.drivers.tas5825 import TAS5825
from audio_server.mediactrl import (
    next_track,
    play_mpv,
    play_pause_track,
    previous_track,
)
from audio_server.processing.chain import enable_filter_chain

I2C_BUS = "/dev/i2c-0"
DSP_I2C_ADDRESS = 0x3B
AMP_I2C_ADDRESS = 0x4E
PD_CONTROLLER_ADDRESS = 0x28

HAT_I2C_BUS = 1
CAP1188_I2C_ADDRESS = 0x2B

DSP_GPIO_ENABLE = 20

g_last_slider: Button | None = None


def slider_handler(amp: TAS5825, button: Button):
    global g_last_slider

    volume_map_db = {
        Buttons.SLIDER_0: -24,
        Buttons.SLIDER_1: -18,
        Buttons.SLIDER_2: -12,
        Buttons.SLIDER_3: -6,
        Buttons.SLIDER_4: 0,
    }

    volume = volume_map_db[button.id]

    # Mute
    if g_last_slider is not None:
        if button.id == Buttons.SLIDER_0 and g_last_slider.id == Buttons.SLIDER_0:
            print("Mute")
            volume = -100
        # Boost
        if button.id == Buttons.SLIDER_4 and g_last_slider.id == Buttons.SLIDER_4:
            print("Boost")
            volume = 6

    g_last_slider = button

    print(f"Setting volume to {volume} dB")
    amp.set_volume(volume)


def play_pause_handler(_: Button):
    print("Play/Pause")
    try:
        play_pause_track()
    except Exception as e:
        print(f"Error playing/pausing: {e}")


def prev_handler(_: Button):
    print("Previous")
    try:
        previous_track()
    except Exception as e:
        print(f"Error playing/pausing: {e}")


def next_handler(_: Button):
    print("Next")
    try:
        next_track()
    except Exception as e:
        print(f"Error playing/pausing: {e}")


def signal_handler(instances: list, signum, frame):
    """Handle Ctrl+C gracefully"""
    print("\nShutting down...")
    for instance in instances:
        print("Setting", instance, "running to False")
        instance.running = False


PER_HOST_DEFAULTS = {
    "nonos-2": {
        "mpv": True,
    },
    "nonos-3": {
        "mpv": True,
    },
}
hostname = socket.gethostname()
HOST_CONFIG = PER_HOST_DEFAULTS.get(hostname, {})


def main(
    init: bool = True,
    reload_filter: bool = True,
    mpv: bool = HOST_CONFIG.get("mpv", True),
):
    i2c = smbus2.SMBus(I2C_BUS)
    dsp = ADAU1452(i2c, DSP_I2C_ADDRESS, DSP_GPIO_ENABLE)
    amp = TAS5825(i2c, AMP_I2C_ADDRESS)
    pd_controller = STUSB4500(i2c, PD_CONTROLLER_ADDRESS, reset_pin=None)
    buttons = CAP1188(HAT_I2C_BUS, CAP1188_I2C_ADDRESS)

    if init:
        dsp.enable()
        amp.enable_shortcut()

    rdo = pd_controller.read_rdo()
    print(rdo)

    # This is quite dangerous
    if init:
        pd_controller.ensure_nvm_custom()
        # set to 0 dB
        amp.set_volume(-12)

    if reload_filter:
        enable_filter_chain()

    for slider in [
        Buttons.SLIDER_0,
        Buttons.SLIDER_1,
        Buttons.SLIDER_2,
        Buttons.SLIDER_3,
        Buttons.SLIDER_4,
    ]:
        buttons.subscribe(
            slider, lambda button: slider_handler(amp, button)
        ).debounce_ms = 250

    buttons.subscribe(Buttons.BOT_MIDDLE, play_pause_handler).debounce_ms = 500
    buttons.subscribe(Buttons.BOT_LEFT, prev_handler).debounce_ms = 250
    buttons.subscribe(Buttons.BOT_RIGHT, next_handler).debounce_ms = 250

    buttons_thread = threading.Thread(target=buttons.run)  # noqa: F841

    signal.signal(
        signal.SIGINT,
        lambda signum, frame: signal_handler([buttons], signum, frame),
    )

    if mpv:
        play_mpv()
    buttons.run()
    # buttons_thread.start()
    # print("Buttons thread started")
    # buttons_thread.join()


if __name__ == "__main__":
    typer.run(main)

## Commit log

2024-11-14 Configure project
    [nonos.kicad_pcb, nonos.kicad_sch]
2024-11-14 structure setup
    [imx8.kicad_pcb, imx8.kicad_sch]
2024-11-19 added layout files
    [pd-controller.kicad_pcb, pd-controller.kicad_sch]
2024-11-19 ic layout complete
    [pd-controller.kicad_pcb]
2024-11-19 add XT30 as output connector
    [pd-controller.kicad_pcb]
2024-11-19 layout checkpoint
    [pd-controller.kicad_pcb]
2024-11-19 refactor to move components into their own files
    [pd-controller.kicad_pcb]
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2024-11-20 update layout
    [pd-controller.kicad_pcb]
2024-11-20 eMMC module interfaces + decoupling caps
    [emmc.kicad_pcb, emmc.kicad_sch]
2024-11-20 Manual net naming
    [emmc.kicad_pcb]
2024-11-20 add extra decoupling caps to 3v3 rail + update layout
    [emmc.kicad_pcb]
2024-11-21 Moved PMIC to this branch, 80% completed power rails for IMX8
    [imx8.kicad_pcb]
2024-11-21 Build errors
    [imx8.kicad_pcb]
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2024-11-21 Placed capacitors for IMX8 power
    [imx8.kicad_pcb]
2024-11-21 update SD2 cap
    [imx8.kicad_pcb]
2024-11-22 RAM connections complete, few build errors to resolve
    [imx8.kicad_pcb, imx8.kicad_sch, pmic.kicad_pcb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]
2024-11-22 Building! started on layout
    [ram.kicad_pcb]
2024-11-22 PMIC building! Net short issue figured out in imx8
    [imx8.kicad_pcb, pmic.kicad_pcb, pmic.kicad_sch]
2024-11-22 Fixing build errors
    [imx8.kicad_pcb, pmic.kicad_pcb]
2024-11-26 Footprint path problems
    [imx8.kicad_pcb, nonos.kicad_pcb]
2024-11-26 layout of capacitors for RAM chip
    [ram.kicad_pcb]
2024-11-26 Update decoupling caps to use for loops and multiple decoupling caps and update layout
    [emmc.kicad_pcb]
2024-11-27 pull in changes from main
    [emmc.kicad_pcb, emmc.kicad_sch, ram.kicad_pcb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]
2024-11-27 pmic layout file
    [pmic.kicad_pcb]
2024-11-27 add library components
    [imx8.kicad_pcb]
2024-11-27 Layout 90% complete
    [pmic.kicad_pcb]
2024-11-27 add extra LDO for 1v2 rail
    [pmic.kicad_pcb]
2024-12-04 TAS5825 component definition
    [amplifier.kicad_pcb, amplifier.kicad_sch, lv2842xlvddcr.kicad_pcb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]
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2024-12-05 add CM4 footprint to layout
    [cm4.kicad_pcb, cm4.kicad_sch]
2024-12-06 add ethernet connector
    [cm4.kicad_pcb, nonos.kicad_pcb]
2024-12-06 refactor for core updates
    [cm4.kicad_pcb, default.kicad_pcb, nonos.kicad_pcb]
2024-12-06 rename pdcontroller folder
    [cm4.kicad_pcb, nonos.kicad_pcb]
2024-12-06 layout sync working
    [cm4.kicad_pcb, nonos.kicad_pcb, pd-controller.kicad_pcb]
2024-12-08 TPS5663 regulator design and layout
    [amplifier-ato.kicad_pcb, default.kicad_pcb, nonos.kicad_pcb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]
2024-12-08 building to layout
    [amplifier-ato.kicad_pcb, amplifier.kicad_pcb, default.kicad_pcb]
2024-12-08 Layout complete
    [amplifier.kicad_pcb]
2024-12-08 make builds for parts
    [capacative_sensor.kicad_pcb, capacative_sensor.kicad_sch, nfc.kicad_pcb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]
2024-12-08 cleanup unused files + standardize naming
    [amplifier-ato.kicad_pcb, imx8.kicad_pcb, imx8.kicad_sch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]
2024-12-09 import copper features to hat board
    [amplifier.kicad_pcb, capacative-sensor.kicad_pcb, hat-board.kicad_pcb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]
2024-12-09 50% layout for hat
    [hat-board.kicad_pcb, nfc.kicad_pcb]
2024-12-09 layout NFC module
    [nfc.kicad_pcb]
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2024-12-09 import antenna and button footprints
    [hat-board.kicad_pcb, nfc.kicad_pcb]
2024-12-09 add capacitive sensor IC and cleanup
    [capacitive_sensor.kicad_pcb, capacitive_sensor.kicad_sch, hat-board.kicad_pcb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]
2024-12-10 add hat interface to nonos board
    [nonos.kicad_pcb]
2024-12-10 builds working
    [amplifier.kicad_pcb, capacitive-sensor.kicad_pcb, hat-board.kicad_pcb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]
2024-12-10 fixed hat-footprint
    [hat-board.kicad_pcb, nonos.kicad_pcb]
2024-12-10 hat board layout complete
    [hat-board.kicad_pcb]
2024-12-11 refactor PD controller + remove params
    [capacative-sensor.kicad_pcb, capacitive-sensor.kicad_pcb, hat-board.kicad_pcb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]
2024-12-11 layout 95%
    [nonos.kicad_pcb, pd_controller.kicad_pcb]
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2025-05-02 cleanup old modules
    [capacitive-sensor.kicad_pcb, cm4.kicad_pcb, cm4.kicad_sch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]
2025-05-02 update syntax to latest for hat board
    [hat-board.kicad_pcb]
2025-05-02 update syntax
    [hat-board.kicad_pcb]
2025-05-02 Update PCB version to kicad9; Disable non-existing builds
    [amplifier.kicad_pcb, capacitive_sensor.kicad_pcb, hat-board.kicad_pcb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]
2025-05-02 fix resistor packages
2025-05-02 fix all cap/resistor packages
2025-05-02 Layout capacitive sensor
    [capacitive-sensor.kicad_pcb]
2025-05-02 Reset nfc layout
    [nfc.kicad_pcb]
2025-05-02 remove new layout
    [hat-board.kicad_pcb]
2025-05-02 Re-address amplifier board
    [amplifier.kicad_pcb]
2025-05-02 kinda fix amp layout
    [nfc.kicad_pcb]
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2025-05-02 Fix amplifier
    [amplifier.kicad_pcb]
2025-05-02 Fix: NFC layout
    - fix packages
    - fix vmid short
    - fix unconnected nets
    - fix linking issues
    [nfc.kicad_pcb]
2025-05-02 remove pour
    [nfc.kicad_pcb]
2025-05-02 run ato
    [nfc.kicad_pcb]
2025-05-03 Fix: hat layout
    Depends on #23
    [hat-board.kicad_pcb]
2025-05-03 layout complete, some drcs to resolve
    [hat-board.kicad_pcb]
2025-05-03 resolve DRCs + cleanup
    [hat-board.kicad_pcb]
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2025-06-28 custom button antenna module
    [CONN-TH_B02B-XASK-1-A-LF-SN.step]
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2025-06-28 fix nonos build
    [57.STEP, DFN1610-2_L1.6-W1.0-P1.05-RD.STEP, IND-SMD_L7.3-W6.8-H3.0.step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]
2025-06-28 reset layout
    [57.STEP, C0402_L1.0-W0.5-H0.5.step, C0603_L1.6-W0.8-H0.8.step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]
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2025-06-28 layout updates, level shifter
    [R0402_L1.0-W0.5-H0.4.step, R0603.STEP, SC-70-6_L2.0-W1.3-H1.0-P0.65.step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]
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2025-06-28 fix via in pad issue
    [hat.kicad_pcb]
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2025-06-28 initial placement and cleanup of ato design
    [57.STEP, C0402_L1.0-W0.5-H0.5.step, C0603_L1.6-W0.8-H0.8.step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]
2025-06-28 position connecotrs and regulator
    [default.kicad_pcb]
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2025-06-29 update touch sensor to v0.1.1
    [R0402_L1.0-W0.5-H0.4.step, hat.kicad_pcb]
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2025-07-03 add ethernet sync pin, tidy up layout, remove auto generated from manually modified footprint
    [default.kicad_pcb]
2025-07-03 remove can_bridge_by_name local trait and use lib trait
    [C0603_L1.6-W0.8-H0.8.step]
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2025-07-04 rebuild with latest ato
    [default.kicad_pcb, hat.kicad_pcb]
2025-07-04 rebuild with released ato
    [default.kicad_pcb, hat.kicad_pcb]
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2025-07-18 Firmware: Bringup (#29)
    * Firmware init commit
    * services; dsp auto bridge
    * filter chain; services; wireplumber
    * move services to --user
    * update procesing
    * buttons
    * mpv
    * auto setup
    * vncpass
    * tuning
    * some setup fixes
    [config.txt]
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
